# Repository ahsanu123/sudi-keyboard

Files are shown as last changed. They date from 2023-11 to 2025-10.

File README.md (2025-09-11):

 <p >
  <a href="">
    
  </a>
  
  <a href="">
    
  </a>
  
  <a href="">
    
  </a>
  
  <a href="https://github.com/ahsanu123/sudi-keyboard/blob/main/LICENSE">
    
  </a>

  <a href=" ">
    
  </a>
  
</p>

<p style="align: right;">
   
</p>
 
# 🌿 _Sudi_ V2

Sudi V2 is custom wireless split keyboard based on NRF52832 Nordic Semiconductor Microcontroller series, each side consist 18 keys 36 in totals, use MCP23017 I2C 
I/O expansion to scan one side of keyboard, and use wire to trasfer data to NRF52. Built in SWD debug port, with Serial Logger based on CH340G. Sudi Have interactive 
RGB LED and OLED 0.91 inch for graphic display. Planned to create 3D print enclosure.

## 💾 hardware 
hardware is designed with Kicad, you can find out hardware design in `pcb-design` folder. 

sudi schematic

**Over simplified workflow**
```mermaid
flowchart TD
    MatrixScanner[Matrix Scanner]
    COR[Chain Of Responsibility]
    FinalReport
    HIDBLEServer[BLE HID Server]

    MatrixScanner --> COR
    COR --> FinalReport
    FinalReport --> HIDBLEServer
```

<details>
  <summary>Casing Design</summary>
 
   

</details>

## 🔥 Progress Log


<details>
  <summary>expand this to see current progress 🍰 </summary>

- ~~try to understand why linker script flash ram address need to change from `0x8000` to `0x4000` [look this thread](https://devzone.nordicsemi.com/f/nordic-q-a/78577/nrf-sdk-pre-built-blinky-hex-works-compiled-hex-does-not-nrf51822)~~, use Zephyr instead.
- ~~update hardware readme.md section, add schematic svg~~
- ~~try to logging with segger jlink rtt~~ at 9 september 2024 22:09
- try to logging with serial logger
- ~~add usb to serial (ch340g) if serial logger worked /or considering to use segger rtt (worked and tested on NRF51822)~~
- ~~add on off switch for board~~
- ~~🦀 Change design to use NRF52832~~
- 🔥 Learn more about Zephyr
- ~~change JTAG debugger to component with less space and same pinout based on JLink v8 pinout.~~
- 🔋 ~~battery/and its charger need adjustment, because NRF5232 power supply range is 1.7 V to 3.6 V , and TP4056 will shutdown on 4.2V. if you add AMS1117 3.3v to regulate it, AMS1117 need at least 4.5V to maintain its 3.3V.~~ (NAH, use buck boost instead)
- 🔋 read about BQ24075 bms datasheet
- 🔋 Read about  MAX17048  datasheet
- 🔋 ~~if we use 1.8V for NRF Voltage supply, how its affect other used component~~
  - 🪔 ~~WS2812 VIO level was not satisfied, based on its datasheet, min supply is 3.5, VIH 0.7*VDD (2.45), VIL 0.3 *VDD (1.05)~~
  - ⚗️ ~~based on MCP23017 datashet its power voltage range is 1.8V to 5.5v, VIH 0.25 VDD + 0.8, VIL 0.8 VDD, so its possible to use MCP23017 with 1.8V NRF voltage supply,~~
  - 🐤 ~~CH340G~~
- ~~🔶check 4 pin crystal compatibility~~
- 🦄 ~~change MCU to use NRF52833?? (power supply 1.7-5.5), usb, price +1 dollar 😥, or (NRF52820 only $2.6348)~~
- 🧀 ~~Recheck Silk Screen and componnent~~
- 💸 ~~Create Manufacture id BOM, and Order it~~ about 70 dollar
- 💸 ~~wait dollar until it lower, and order all needed component.~~ shit!!!, dollar does not decline
- ⚽ ~~Final Re-Inspection~~ not doing it actually
- 💸 ~~ordered pcb. 5 Pcs for $15.72 with shipment 7.02 dollar and the pcb is 8.7, still wait for tax. ⏰ 19 januari 2025 at 22:16,~~ arrived in 7 Februari
- 👘 Ordering Component 58 dollar free shipping ( shipping is 7 dollar) , ⏰ 8 Februari 2025
- 💼 Casing - Left Right Connector
- 💼 Casing - top fastener
- 💼 Casing - Battery Holder
- 28 April 2025 ⏰ 05:47, finish one side small component soldering, there is still a lot solder bridge, need to recheck before aplying power
- 🐞 **BUG**, 1 Mei 2025 ⏰17:29, cell pin need to connect into battery pin, not 3.3v

  
  
- 🐞 **BUG**, 9 Mei 2025 ⏰ 20:18 current version 2 gerber used for manufacturing pcb is not updated, there is shorted between 3.3v and gnd
- 🐞 **BUG**, 13 Mei 2025 ⏰ 06:52 look and re-calculate inductor 5v buck-boost, when its at full load (all ws28 12 is on) inductor is burn, but ic is not.

> change inductor to use power inductor like VLF4012-2R2 (2.2uH, 1.5A), or choose same capacitance with higher current rate.
>
> look this [lcsc power inductor](https://www.lcsc.com/product-detail/Power-Inductors_MetalLions-MTQH201608S2R2MBT_C17701122.html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)

- 🎰 able to run and flash RMK example with jlink and probe-rs ⏰ 9 Mei 2025, 20:19
- basic setup on WSL, so able to develop in WSL ⏰ 20 Mei 2025, 05:26

  to debugging you need bridge usb device from windows to wsl with `usbipd`

  ```shell
  C:\Windows\System32> usbipd list
  Connected:
  BUSID  VID:PID    DEVICE                                                        STATE
  1-1    feed:0ffa  USB Input Device                                              Not shared
  1-2    0000:3825  USB Input Device                                              Not shared
  1-4    0bda:0129  Realtek USB 2.0 Card Reader                                   Not shared
  1-5    13d3:56cb  USB2.0 HD IR UVC WebCam                                       Not shared
  1-6    1366:0101  J-Link driver                                                 Not shared
  1-10   8087:0026  Intel(R) Wireless Bluetooth(R)                                Not shared

  Persisted:
  GUID                                  DEVICE

  C:\Windows\System32> usbipd bind --busid 1-6

  C:\Windows\System32> usbipd attach --wsl --busid 1-6
  usbipd: info: Using WSL distribution 'Arch' to attach; the device will be available in all WSL 2 distributions.
  usbipd: info: Detected networking mode 'nat'.
  usbipd: info: Using IP address 172.27.144.1 to reach the host.

  C:\Windows\System32>
  ```

  then you can access the usb device as in linux

- 24 Mei 2025, trying to run trouble bas example, its give good sign, even 5v sepic is died for now -> https://github.com/embassy-rs/trouble/blob/main/examples/apps/src/ble_bas_peripheral.rs ⏰ 09:01 

- 25 Mei 2025, able to read uuid for battery level on trouble bas example, also create basic reading uuid with bleak python library, but its really intermitent, bluez is more robust, several note to use and connect bluez with device.

also flashed firmware is from trouble example, current v2 firmware is compiled but not running, 🪞 need to investigate it

```shell
$ bluetoothctl
hci0 new_settings: powered bondable ssp br/edr le secure-conn
Agent registered

[bluetoothctl]> connect FF:E4:05:1A:8F:FF
[bluetoothctl]> disconnect FF:E4:05:1A:8F:FF
[bluetoothctl]> menu gatt
[bluetoothctl]> list-attributes
[bluetoothctl]> select-attribute /org/bluez/hci0/dev_FF_E4_05_1A_8F_FF/service0020/char0021
[bluetoothctl]> read
[bluetoothctl]>
```

- 3 Juli 2025, reading more about trouble, here is `trouble-host-macro` documentation located https://docs.rs/trouble-host-macros/latest/trouble_host_macros/ , here are some note
  - Peripherals may use **GATT** (Generic Attribute Profile) to expose **services** and **characteristics**,
  - still many question about why linker cant linking ble exampl (stack is overflow) even though its identical with example
  - this error ` cannot move location counter backwards (from 3ffdeca8 to 3ffdc000` is because `embassy-executor` `task-arena-<size>` i am not sure why and what value its shouuld be. but without defining task arena its compiled but `panic` on runtime.
  - ok, i find out making `embassy-executor` have `embassy-executor = { version = "0.7.0", features = ["task-arena-size-8192"]}` will make it compiled 😙, need to learn what is that.

finally at ⏰ 21:46 its compiled and able to run, its discoverable with phone 


- 23 Agustus 2025, finally my first SUDI was broke (MCU) and I must finish SUDI v2 for working.
- 24 agustus 2025, basic bas for nrf is compiled and flashed, ⏰ 13:25 
  

  ⏰ 21:29, able to advertise device as bluetooth hid, but still cant establishing connection to keyboard,
  need to understand how HID keyboard is connected in USB and in BLE.

- 11 September 2025, after reading more about BLE spesification, to more understand what each endpoint / characteristic does in BLE HID, you need to:
  * read characteristic code from [bluetooth assigned number](http://bluetooth.com/wp-content/uploads/Files/Specification/HTML/Assigned_Numbers/out/en/Assigned_Numbers.pdf). for example look at `2a4a` from `hid_info` property in this struct (take from RMK github)
    ```rust
    #[gatt_service(uuid = service::HUMAN_INTERFACE_DEVICE)]
    pub(crate) struct HidService {
        #[characteristic(uuid = "2a4a", read, value = [0x01, 0x01, 0x00, 0x03])]
        pub(crate) hid_info: [u8; 4],
        #[characteristic(uuid = "2a4b", read, value = KeyboardReport::desc().try_into().expect("Failed to convert KeyboardReport to [u8; 67]"))]
        pub(crate) report_map: [u8; 67],
        #[characteristic(uuid = "2a4c", write_without_response)]
        pub(crate) hid_control_point: u8,
        #[characteristic(uuid = "2a4e", read, write_without_response, value = 1)]
        pub(crate) protocol_mode: u8,
        #[descriptor(uuid = "2908", read, value = [0u8, 1u8])]
        #[characteristic(uuid = "2a4d", read, notify)]
        pub(crate) input_keyboard: [u8; 8],
        #[descriptor(uuid = "2908", read, value = [0u8, 2u8])]
        #[characteristic(uuid = "2a4d", read, write, write_without_response)]
        pub(crate) output_keyboard: [u8; 1],
    }
    ```
  * search `2a4a` on BLE Assigned number you will find **HID Information**
    
  * from that information (HID Information), look at [HID over gatt profile](https://www.bluetooth.com/specifications/specs/hid-over-gatt-profile-1-0/)
    
  * it will give you basic information of what is **HID information** is
  * to understand more about what value should provided by your device, you can continue to [Device Class Definition for HID](https://www.usb.org/sites/default/files/hid1_11.pdf), and try to search keyword from _HID over gatt profile_ description, for example `bcountryCode`, search on _Device class definition for HID_ then you will find **HID Descriptor**
    
  * from that information you can conclude `value = [0x01, 0x01, 0x00, 0x03])]` is HID Descriptor, then
  * `0x01` is _bLength_
  * `0x01` is _bDescriptorType_
  * `0x00` is _bcdHID_
  * `0x03` is _bCountryCode_
</details>

## 💳 Reference 

- [RMK - Rust Keyboard Firmware](https://github.com/HaoboGu/rmk/tree/main)   
- [Buck Boost for 3.3v](https://www.eevblog.com/forum/projects/regulating-lipo-battery-to-3-3v/)

<sup>🔥 make it V2 - 19 juni 2024 10:49</sup>

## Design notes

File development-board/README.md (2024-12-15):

## SUDI Development Board

Development board intended to understanding NRF52 nordic series for wireless keyboard, 
with Battery Management System (BMS), Bluetooth Low Energy Communication, USB, Vsense and 
LED Matrix.

## Description 

initial design decision, 

- NRF52820(5v tolerant, and USB, 256 kB flash, 32 kB RAM, QFN-40-EP(5x5), $2.6)
- NRF52832(**No** 5v tolerant, and **No** USB, 512/256 kB flash, 64/32 kB RAM, QFN-48-EP(6x6), $2.75)
- NRF52833QDXX(5v tolerant, and USB, 512 kB flash, 128 kB RAM, QFN-40-EP(5x5), $3.59)
- NRF52840(5v tolerant, and USB, 1 MB flash, 256 kB RAM, WLCSP-94(3.5x3.6) More difficult to Solder but most complete feature, $5.22)
- Add BMS into board 
- add IO expander, use MCP23017 smd
- board able to drive ws2812b (min voltage 3.5)
- vsense ic MAX17048
- switch to test 
- led for indicator 
- give all pin connector 
- usb with protection 
- uart 
- i2c 

## Note 

- [NRF51822 bluetooth module pin](https://quartzcomponents.com/cdn/shop/products/NRF51822-BLE-Module_1200x1200.jpg?v=1653290384)
  
```schell
left (from top perspectife, count from bottom)      Right (from top perspectife, count from bottom)  
PO3                                                 PO105                                            
PO4                                                 PO106                                            
PO1                                                 PO107                                            
PO2                                                 PO108                                            
PO30                                                PO109                                            
PO0                                                 PO110                                            
VDD                                                 PO111                                            
GND                                                 PO112                                            
PO28                                                PO003                                            
PO29                                                PO114                                            
NC                                                  PO015                                            
NC                                                  PO116                                            
PO24                                                SDA                                              
PO25                                                SCLK                                             
PO22                                                PO117                                            
PO23                                                PO119                                            
GND                                                 PO118                                            
PO21                                                PO200                                            

```

## Reference 

- [ebastler/zmk-designguide](https://github.com/ebastler/zmk-designguide)

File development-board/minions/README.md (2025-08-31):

# Minions


[Assembly View](https://kicanvas.org/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)

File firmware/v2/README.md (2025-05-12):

# Introduction

## Pinout 



## Note 

- to custom cargo subcommand use `Makefile.toml` with `cargo-make`, `cargo make some-task`

## Reference 

- [flash softdevice (bluetooth stack by nordic, closed source), only flash once](https://github.com/embassy-rs/nrf-softdevice#running-examples)

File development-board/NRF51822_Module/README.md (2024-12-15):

## Introduction 

Place to save Zephyr learning with NRF51822 Module

## Setup 

- after install dependencies like cmake, devicetree, and python
- create new python Environment with `venv` on home directory for example (`~/zephyr-sdk/`), 
- run `python -m venv ~/zephyr-sdk/.venv/`
- then activate it with `source ~/zephyr-sdk/.venv/bin/activate`
- next install **west** with `pip`, run `pip install west`

## Note 

- change default Zephyr SDK installation folder with env variable [ZEPHYR_SDK_INSTALL_DIR](https://docs.zephyrproject.org/latest/develop/env_vars.html#envvar-ZEPHYR_SDK_INSTALL_DIR) 
- important Zephyr concept

> [!NOTE]
> In this document, we’ll assume:
> your application directory, `<app>`, is something like `<home>/zephyrproject/app`
> its build directory is `<app>/build`
> These terms are defined below. On Linux/macOS, `<home>` is equivalent to `~`. On Windows, it’s `%userprofile%`.
> Keeping your application inside the workspace (`<home>/zephyrproject`) makes it easier to use west build and other commands with it. (You can put your application anywhere as long as [ZEPHYR_BASE](https://docs.zephyrproject.org/latest/develop/application/index.html#important-build-vars) is set appropriately, though.)

| Application type | <app> location |
|---|---|
| repository | zephyr repository |
| workspace | west workspace where Zephyr is installed |
| freestanding | other locations |

### Note on Make Custom Board (Porting)

root folder is `app`

```shell
boards/
soc/
CMakeLists.txt
prj.conf
README.rst
src/
```

```shell
.
├── boards
│   └── vendor
│       └── my_custom_board
│           ├── doc
│           │   └── img
│           └── support
└── src
```

The contents of my_custom_board should follow the same guidelines for any Zephyr board,
```shell
// inside board folder name (/boards/<vendor>/<board-name>/)
my_custom_board_defconfig
my_custom_board.dts
my_custom_board.yaml
board.cmake
board.h
CMakeLists.txt
doc/
Kconfig.my_custom_board
Kconfig.defconfig
support/
```

- **Board YAML**

> [!NOTE]
> The board YAML file describes the board at a high level. This includes the SoC, board variants, and board revisions.
> Detailed configurations, such as hardware description and configuration are done in devicetree and Kconfig.

## Log

- Make personal note on how to setup Zephyr Environment with poetry

## Reference 

- [official bluetooth learning resource](https://www.bluetooth.com/bluetooth-resources/?types=study-guide)
- [zephyr board porting guide](https://docs.zephyrproject.org/latest/hardware/porting/board_porting.html)
- [Custom Board devicetree and SOC Definitions](https://docs.zephyrproject.org/latest/develop/application/index.html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)

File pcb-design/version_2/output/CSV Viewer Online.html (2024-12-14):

| Id | Designator | Footprint | Quantity | Designation | Supplier and ref | | H
1 | 1 | C56,C11,C15 | C_0805_2012Metric_Pad1.18x1.45mm_HandSolder | 3 | 0.1uF / 100nF | | | in stock
2 | 2 | K16,K9,K8,K18,K12,K14,K7,K6,K5,K2,K10,K13,K3,K15,K17,K4,K11,K1 | Kailh_socket_MX_optional_reversible_platemount | 18 | KEYSW | | | buy local
3 | 3 | FB1 | L_0603_1608Metric_Pad1.05x0.95mm_HandSolder | 1 | 60R@100Mhz | | | ok
4 | 4 | R10,R17,R15 | R_0805_2012Metric_Pad1.20x1.40mm_HandSolder | 3 | 1K | | | in stock
5 | 5 | TP16 | TestPoint_Pad_D1.0mm | 1 | 29 | | | not need
6 | 6 | C51,C42,C41,C43,C40,C19,C39,C20,C54,C44,C45,C52,C35,C48,C53,C47,C50,C46,C49,C55,C38 | C_0805_2012Metric_Pad1.18x1.45mm_HandSolder | 21 | 100nF | | | in stock
7 | 7 | J1,J5 | USB_C_Receptacle_GCT_USB4125-xx-x-0190_6P_TopMnt_Horizontal | 2 | SIDE_CON | | | in stock
8 | 8 | D17,D18,D25,D8,D36,D29,D31,D9,D38,D10,D24,D19,D30,D23,D13,D37,D12,D11 | LED_WS2812B-2020_PLCC4_2.0x2.0mm | 18 | WS2812B | | | ok
9 | 9 | C3,C1 | C_0805_2012Metric_Pad1.18x1.45mm_HandSolder | 2 | 4.7uF | | | ok
10 | 10 | FID9,FID2,FID3,FID6,FID7,FID5,FID1,FID8,FID4 | Fiducial_1mm_Mask3mm | 9 | Fiducial | | | -
11 | 11 | D26,D33,D2,D21,D34,D14,D7,D1,D20,D15,D5,D27,D3,D16,D35,D22,D28,D6 | D_SOD123_axial-dual | 18 | 1N4148 | | | ok
12 | 12 | H2,H1,H5,H3,H4,H7,H6 | MountingHole_3.2mm_M3_DIN965_Pad | 7 | MountingHole_Pad | | | -
13 | 13 | TP5 | TestPoint_Pad_D1.0mm | 1 | 4 | | | not need
14 | 14 | R4,R3 | R_0805_2012Metric_Pad1.20x1.40mm_HandSolder | 2 | 5K1 | | | ok
15 | 15 | C18,C8 | C_0805_2012Metric_Pad1.18x1.45mm_HandSolder | 2 | 12pF | | | ok
16 | 16 | TP17 | TestPoint_Pad_D1.0mm | 1 | 30 | | | not need
17 | 17 | R11 | R_0805_2012Metric_Pad1.20x1.40mm_HandSolder | 1 | 1k | | | in stock
18 | 18 | TP9 | TestPoint_Pad_D1.0mm | 1 | 22 | | | not need
19 | 19 | R12,R5 | R_0805_2012Metric_Pad1.20x1.40mm_HandSolder | 2 | 100k | | | in stock
20 | 20 | AE1 | Texas_SWRA117D_2.4GHz_Left | 1 | 2.4GHz | | | -
21 | 21 | C2 | C_0805_2012Metric_Pad1.18x1.45mm_HandSolder | 1 | 10uF/5V | | | in stock
22 | 22 | TP13 | TestPoint_Pad_D1.0mm | 1 | 26 | | | not need
23 | 23 | R1,R2 | R_0805_2012Metric_Pad1.20x1.40mm_HandSolder | 2 | 4K7 | | | in stock
24 | 24 | TP11 | TestPoint_Pad_D1.0mm | 1 | 24 | | | not need
25 | 25 | P1 | USB_C_Receptacle_GCT_USB4105-xx-A_16P_TopMnt_Horizontal | 1 | USB_C_Plug_USB2.0 | | | ok
26 | 26 | TP3 | TestPoint_Pad_D1.0mm | 1 | 2 | | | not need
27 | 27 | C21 | C_0805_2012Metric_Pad1.18x1.45mm_HandSolder | 1 | 0.8pF | | | in stock
28 | 28 | R14 | R_0805_2012Metric_Pad1.20x1.40mm_HandSolder | 1 | 1.13k | | | in stock
29 | 29 | U7 | QFN-48-1EP_6x6mm_P0.4mm_EP4.6x4.6mm | 1 | nRF52832-QFxx | | | ok
30 | 30 | TP15 | TestPoint_Pad_D1.0mm | 1 | 28 | | | not need
31 | 31 | Y1 | Crystal_SMD_2016-4Pin_2.0x1.6mm | 1 | 32MHz_CF4032M00020001 | | | ok
32 | 32 | U5 | VQFN-16-1EP_3x3mm_P0.5mm_EP1.6x1.6mm | 1 | BQ24075RGT_DPPM | | | ok
33 | 33 | C36 | C_0805_2012Metric_Pad1.18x1.45mm_HandSolder | 1 | 100nF/NC | | | in stock
34 | 34 | Q2 | SOT-23 | 1 | PJA3405_(G1,D3,S2) | | | ok
35 | 35 | D4 | LED_0805_2012Metric_Pad1.15x1.40mm_HandSolder | 1 | green | | | ok
36 | 36 | TP18 | TestPoint_Pad_D1.0mm | 1 | 31 | | | not need
37 | 37 | C37 | C_0805_2012Metric_Pad1.18x1.45mm_HandSolder | 1 | 1uF | | | in stock
38 | 38 | TP4 | TestPoint_Pad_D1.0mm | 1 | 3 | | | not need
39 | 39 | R6 | R_0805_2012Metric_Pad1.20x1.40mm_HandSolder | 1 | 46.4K | | | in stock
40 | 40 | TP8 | TestPoint_Pad_D1.0mm | 1 | 20 | | | not need
41 | 41 | TP2 | TestPoint_Pad_D1.0mm | 1 | 1 | | | not need
42 | 42 | TP1 | TestPoint_Pad_D1.0mm | 1 | 0 | | | not need
43 | 43 | TP6 | TestPoint_Pad_D1.0mm | 1 | 5 | | | not need
44 | 44 | SW3 | SW_SPDT_PCM12 | 1 | PWR_SWITCH | | | ok
45 | 45 | TP12 | TestPoint_Pad_D1.0mm | 1 | 25 | | | not need
46 | 46 | R7 | R_0805_2012Metric_Pad1.20x1.40mm_HandSolder | 1 | 1.18k | | | in stock
47 | 47 | TP10 | TestPoint_Pad_D1.0mm | 1 | 23 | | | not need
48 | 48 | D32 | LED_0805_2012Metric_Pad1.15x1.40mm_HandSolder | 1 | red | | | ok
49 | 49 | Q1 | SOT-23 | 1 | PJA3404_(G1,D3,S2) | | | ok
50 | 50 | TP7 | TestPoint_Pad_D1.0mm | 1 | 19 | | | not need
51 | 51 | L3 | L_0603_1608Metric_Pad1.05x0.95mm_HandSolder | 1 | 3.9nH | | | ok
52 | 52 | J3 | PinHeader_1x04_P2.54mm_Vertical | 1 | 0.91 OLED | | | -
53 | 53 | TP14 | TestPoint_Pad_D1.0mm | 1 | 27 | | | not need
54 | 54 | SW4 | SW_SPDT_PCM12 | 1 | 5V_EN | | | ok
55 | 55 | J2 | PinHeader_1x04_P2.54mm_Horizontal | 1 | SWD_JLINK | | | -
56 | 56 | C17,C13,C14,C12,C16,C4 | C_0805_2012Metric_Pad1.18x1.45mm_HandSolder | 6 | 10uF | | | ok
57 | 57 | U4 | SOIC-16_3.9x9.9mm_P1.27mm | 1 | CH340C | | | in stock
58 | 58 | SW1 | SW_Push_1P1T_NO_6x6mm_H9.5mm | 1 | RST | | | in stock

| Id | Designator | Footprint | Quantity | Designation | Supplier and ref | | H

1

2

3

4

5

6

7

8

9

10

11

12

13

14

15

16

17

18

19

20

21

22

23

24

25

26

27

28

29

30

31

32

33

34

35

36

37

38

39

40

41

42

43

44

45

46

47

48

49

50

51

52

53

54

55

56

57

58

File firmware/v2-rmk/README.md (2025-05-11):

# ⌨️ Sudi With RMK 

Try to understand and implement RMK for Sudi, make contribution if possible.

## 🦀 RMK Note 

**RMK File Summary**

- 📁 ble
- 📁 config
- 📁 input_device
- 📁 split
- 📁 storage
- 📁 usb
- 📁 via
- 🍉 action.rs -> contain struct and function to convert action into real binary keyboard command
- 🍉 boot.rs -> contain basic boot operation, jump to bootloader and reboot keyboard
- 🍉 channel.rs -> contain multithread channel, signal, mutex and pubsub. mostly from embassy_sync lib
- 🍉 combo.rs -> contain struct to implement keyboard combo feature
- 🍉 direct_pin.rs -> contain struct that define structure of keyboard matrix,
> [!NOTE]
>
> directPinMatrix contain 2 method, `read_event` and `wait_for_key`.
>
> if `async_matrix` is use, `read_event` will wait for key (wait for keyboard user to typing on key), based on setting, switch matrix may active low or active high, inside  `wait_for_key` program will use `select_slice` from `embassy_future::select` to wait any key to be low/high then it will continue process in `read_event` method.
>
> if `async_matrix` is not used program will run loop scanning inside `read_event` method every `100 micro second` as indicated by `Timer::after_micros(100).await;` it will use debouncer to detect if debounce happen, then it will return `Event`.
> 
> (need read more about this method, and its logic)

- 🍉 event.rs -> contain struct of Event, event is not only coming from keyboard typing, but also several other type.
- 🍉 fmt.rs -> contain format for doing debug, loging, or print information
- 🍉 fork.rs -> not trully understand what is this 
- 🍉 hid.rs -> contain HID struct and trait to be implemented by concrete peripheral like USB or BLE 
- 🍉 hid_state.rs -> contain HID state like, HID modifier, HID Mouse button (need read more about HID)
- 🍉 keyboard.rs -> i think its center logic, its big file and lot of test too, need to deep dive into it.
- 🍉 keyboard_macro.rs -> define sturcture, logic and test of _keyboard macro_ (key combination / sequence operation with one key press)
- 🍉 keycode.rs -> contain all HID keycode
- 🍉 keymap.rs -> define logic of keymap (key layer, what key will do when it pressed)
- 🍉 layout_macro.rs -> contain lot of macro, still dont understand well on reading `macro_rules`
- 🍉 lib.rs -> contain library utility function, and exported API to enduser
- 🍉 light.rs -> contain led controller, need read more about logic on this file 
- 🍉 matrix.rs -> i think its high level for abstraction of `direct_pin.rs`
- 🍉 state.rs -> contain keyboard connection state (BLE, or USB), its like, its keyboard connected??

## 🍈 References 

- [cfg attribute](https://doc.rust-lang.org/rust-by-example/attribute/cfg.html)

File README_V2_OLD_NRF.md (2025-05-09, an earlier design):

<h1 align="center">🌿 <i>SUDI</i> Keyboard V2</h1>
<p style="align: right;">
   
  
</p>

<p >
  <a href="">
    
  </a>
  <a href="">
    
  </a>
  <a href="">
    
  </a>
  <a href="https://github.com/ahsanu123/sudi-keyboard/blob/main/LICENSE">
    
  </a>
</p>

Sudi V2 is custom wireless split keyboard based on NRF52832 Nordic Semiconductor Microcontroller series, each side consist 18 keys 36 in totals, use MCP23017 I2C I/O expansion to scan one side of keyboard, and use wire to trasfer data to NRF52. Built in SWD debug port, with Serial Logger based on CH340G. Sudi Have interactive RGB LED and OLED 0.91 inch for graphic display. Planned to create 3D print enclosure.\

<details>
  <summary>Casing Design</summary>
 
   

</details>

## 🖨️ Compile And Flash

🍮 Step to Compile and flash (Zephyr)

first activate your python environtment (i use micromamba, sudiv2 is environtment on my linux pc) 
```shell
micromamba activate sudiv2
```
next build with `west` 
```shell
west build -b sudi app
```

---

🍮 Step to Compile and flash (Makefile and Native toolchain)

1. because we use makefile just call `make` in root directory
2. after complete you can use jlink or stlink to program your binary, nrf can programmed with swd
3. to use jlink you can use this command `sudo JLinkExe -Device NRF51822_XXAA -IF swd -AutoConnect 1 -Speed 1000` then you can load binary file with `loadfile ./path/to/file.out` (we use .out instead .elf)
4. to use stlink you can use this [script](https://github.com/vedderb/nrf51_vesc) you need change .out path
```shell
#!/bin/bash
openocd -f openocd.cfg -c "init" \
  -c "halt" \
  -c "nrf51 mass_erase" \
  -c "program ./build/binary.out verify reset exit"
```

## 🐞 Debugging Step

there is many way to debug NRF microcontroller, i will use JLink V8. first connect Jlink SWD to NRF MCU. 

after compile, upload your binary with jlink 
```shell
 sudo JLinkExe -Device NRF51822_XXAA -IF swd -AutoConnect 1 -Speed 1000 // change device based on your device
```
next inside `JLinkExe` run load binary file with `loadfile ./path/to/your/file.elf` (you can automate this with text script, but i just want write it to remember).

then start `openocd` debug server with

```shell
sudo openocd -f interface/jlink.cfg  -c "transport select swd; adapter speed 1000" -f target/nrf51.cfg &
```

finally you can start your debugger in this case we use `arm-none-eabi-gdb` then connect to target with this step (withtout `>`)

```shell
> file ./path/to/your/file.elf
> break main.c:22 //optional
> target extended-remote :3333 // default port for openocd debug server
> // devices connected
```

if debugger will _stuck_ on `fail.c` after _arch interrupt lock_ there maybe some bad/wrong setting(recheck your config).

<details>
  <summary>🍷 Old Debug Step (here for history purpose only)</summary>
  
  to debug you can use openocd + stlink, openocd + jlink, ozone. make sure to change `gdbcmd.txt` based on your setting (gdb port, output filename, etc.)

```shell
//🗒️🗒️🗒️🗒️ gdbcmd.txt 🗒️🗒️🗒️🗒️🗒️
// you need to connect into server first before choosing `file` to debug, 
target extended-remote :3333
file ./build/nrf51822_xxaa.out
break main
continue
```

- openocd + stlink
  first start openocd gdb server with this command
  
 ```shell
   sudo openocd -f interface/stlink-v2.cfg -f target/nrf51.cfg &
  ```
 
  next you can use `arm-none-eabi-gdb` to debug your program, run this command on other terminal `arm-none-eabi-gdb -x gdbcmd.txt`

- openocd + jlink
 you can start jlink gdb server with this command `sudo JLinkGDBServerExe &` then choose device and peripheral (swd) , or you can start server with openocd

 ```shell
  sudo openocd -f interface/jlink.cfg  -c "transport select swd; adapter speed 1000" -f target/nrf51.cfg
  ```

  next you can use `arm-none-eabi-gdb` to debug your program, run this command on other terminal `arm-none-eabi-gdb -x gdbcmd.txt`
  
- ozone
  last option you can use segger ozone. (not trying yet)
</details>

<details>
  <summary>expand this if you curious (historic purpose only)</summary>
  
- **Ok!!**, I need 2 days (on my weekend) for figuring out how compile in NRF51 mcu with NRF5 SDK (at time of writing NRF5 SDK was obsolete/under maintenance only by Nordic Semiconductor). 

- **FIRST** as far as i understand NRF51 MCU series only work with NRF5 sdk below version 12 (never complete compiling with version above 12), so you need to download NRF5 SDK version 12 or below. 

- **SECOND** i have try to compile nrf project with cmake, but fail and make me stress, so i stick with makefile

- **THIRD** debugging with `arm-eabi-none-gdb` a bit tricky you need perform several command before program go into breakpoint.

- **FOURTH** you need to use old gcc compiler (gcc-arm-none-eabi-4_9-2015q3-20150921-linux.tar.bz2), there is some problem in linking process when you use new gcc version like v14
</details>

## 💾 hardware 
hardware is designed with Kicad, you can find out hardware design in `pcb-design` folder. 
sudi schematic

casing is designed with PTC CREO, and use cutting acrylic (not uploaded/complete yet but planned)  
<details>
  <summary>Expand Me </summary>
  <p align="center">
  <a href="https://youtu.be/LN7CI2rUKP8">
    
  </a>
</p>

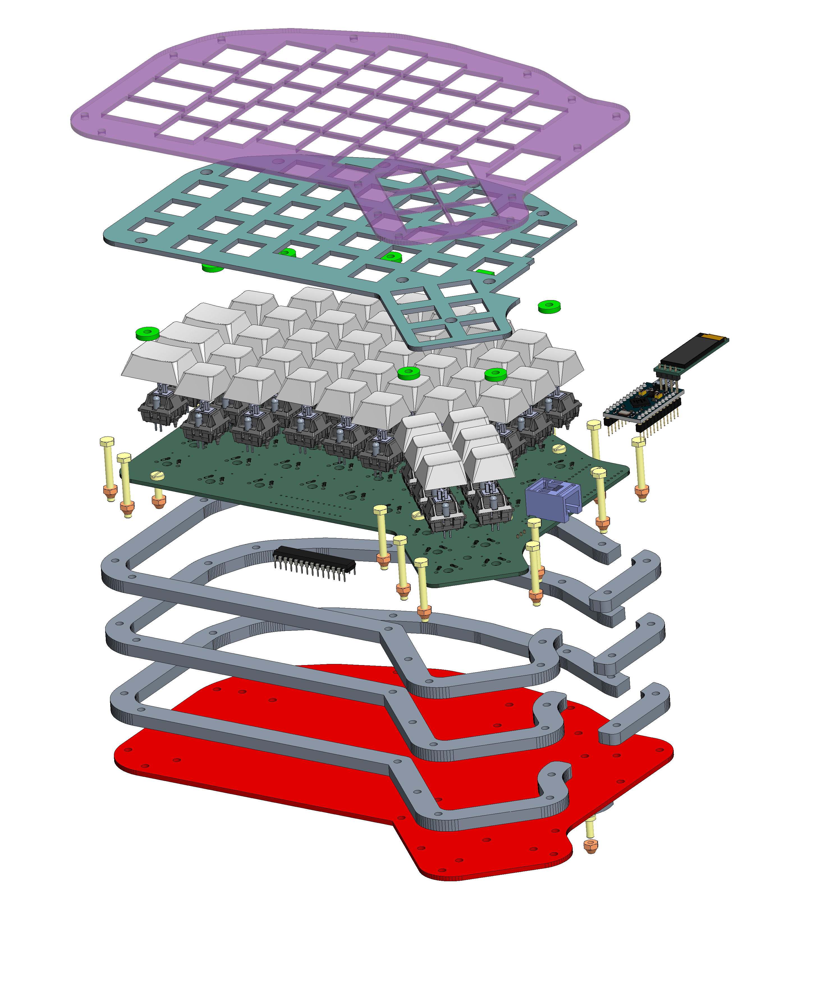
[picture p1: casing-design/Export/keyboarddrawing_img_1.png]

</details>

## 🧁 Install Module In Zephyr
zephyr use _manifest_(west.yml) to setting what module used. to automatic install module, add module name after `name-allowlist`, here is example.

```yaml
manifest:
  self:
    west-commands: scripts/west-commands.yml

  remotes:
    - name: zephyrproject-rtos
      url-base: https://github.com/zephyrproject-rtos

  projects:
    - name: zephyr
      remote: zephyrproject-rtos
      revision: main
      import: 
        name-allowlist:
          - cmsis      # required by the ARM port
          - hal_nordic # required by the custom_plank board (Nordic based)
          - hal_stm32  # required by the nucleo_f302r8 board (STM32 based)
          - segger # add another component based on module repository

```

after edit `west.yml` run `west update`, `west` will update the module based on manifest.

`west` will search to this [repo](https://github.com/zephyrproject-rtos/zephyr/tree/main/modules), then download and install it based on your zephyr root.

after you installed (download) zephyr module you can enable with `menuconfig`, you can run menuconfig with 
```shell
west build -t menuconfig
```

## 🧱 TODO List 


- ~~try to understand why linker script flash ram address need to change from `0x8000` to `0x4000` [look this thread](https://devzone.nordicsemi.com/f/nordic-q-a/78577/nrf-sdk-pre-built-blinky-hex-works-compiled-hex-does-not-nrf51822)~~, use Zephyr instead.
- ~~update hardware readme.md section, add schematic svg~~
- ~~try to logging with segger jlink rtt~~ at 9 september 2024 22:09
- try to logging with serial logger
- ~~add usb to serial (ch340g) if serial logger worked /or considering to use segger rtt (worked and tested on NRF51822)~~
- ~~add on off switch for board~~
- ~~🦀 Change design to use NRF52832~~
- 🔥 Learn more about Zephyr
- ~~change JTAG debugger to component with less space and same pinout based on JLink v8 pinout.~~
- 🔋 ~~battery/and its charger need adjustment, because NRF5232 power supply range is 1.7 V to 3.6 V , and TP4056 will shutdown on 4.2V. if you add AMS1117 3.3v to regulate it, AMS1117 need at least 4.5V to maintain its 3.3V.~~ (NAH, use buck boost instead)
- 🔋 read about BQ24075 bms datasheet
- 🔋 Read about  MAX17048  datasheet
- 🔋 ~~if we use 1.8V for NRF Voltage supply, how its affect other used component~~
  - 🪔 ~~WS2812 VIO level was not satisfied, based on its datasheet, min supply is 3.5, VIH 0.7*VDD (2.45), VIL 0.3 *VDD (1.05)~~
  - ⚗️ ~~based on MCP23017 datashet its power voltage range is 1.8V to 5.5v, VIH 0.25 VDD + 0.8, VIL 0.8 VDD, so its possible to use MCP23017 with 1.8V NRF voltage supply,~~
  - 🐤 ~~CH340G~~
- ~~🔶check 4 pin crystal compatibility~~
- 🦄 ~~change MCU to use NRF52833?? (power supply 1.7-5.5), usb, price +1 dollar 😥, or (NRF52820 only $2.6348)~~
- 🧀 ~~Recheck Silk Screen and componnent~~
- 💸 ~~Create Manufacture id BOM, and Order it~~ about 70 dollar
- 💸 ~~wait dollar until it lower, and order all needed component.~~ shit!!!, dollar does not decline
- ⚽ ~~Final Re-Inspection~~ not doing it actually
- 💸 ~~ordered pcb. 5 Pcs for $15.72 with shipment 7.02 dollar and the pcb is 8.7, still wait for tax. ⏰ 19 januari 2025 at 22:16,~~ arrived in 7 Februari
- 👘 Ordering Component 58 dollar free shipping ( shipping is 7 dollar) , ⏰ 8 Februari 2025
- 💼 Casing - Left Right Connector
- 💼 Casing - top fastener
- 💼 Casing - Battery Holder
- 28 April 2025 ⏰ 05:47, finish one side small component soldering, there is still a lot solder bridge, need to recheck before aplying power
- 🐞 **BUG**, 1 Mei 2025 ⏰17:29, cell pin need to connect into battery pin, not 3.3v
- 🐞 **BUG**, 9 Mei 2025 ⏰ 20:18 current version 2 gerber used for manufacturing pcb is not updated, there is shorted between 3.3v and gnd
- 🎰 able to run and flash RMK example with jlink and probe-rs ⏰ 9 Mei 2025, 20:19

  

## 💳 Reference 
- [you need to read this if blink example not working](https://devzone.nordicsemi.com/f/nordic-q-a/78577/nrf-sdk-pre-built-blinky-hex-works-compiled-hex-does-not-nrf51822)
- [NRF51 Series Documentation](https://www.nordicsemi.com/Products/nRF51822/GetStarted)
- [Redox-Keyboard](https://github.com/mattdibi/redox-keyboard) i use redox schematic for initial design  
- [MCP23017 datasheet](reference/MCP23017-20001952c.pdf) and add my *initial redox sch* with MCP23017
- [Zephyr Devices Tree](https://docs.zephyrproject.org/latest/build/dts/)
- [Buck Boost for 3.3v](https://www.eevblog.com/forum/projects/regulating-lipo-battery-to-3-3v/)
- [RMK - Rust Keyboard Firmware](https://github.com/HaoboGu/rmk/tree/main)

<sup>🔥 make it V2 - 19 juni 2024 10:49</sup>

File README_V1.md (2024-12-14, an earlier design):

# ⌨️ Sudi Keyboard V1


<!-- <img style="align: right; width: 50vw;" src="./pcb-design/output/sudi-redox-clone-RIGHT.png"> -->
Sudi keyboard is custom split keyboard based on QMK, its use MCP23017 for scanning key matrix on right side, use promicro for scanning left side. right now sudi is not come with rgb led but its planned.
each side consist 42 standard mechanical key, 84 in total. 

## 🔋 how to compile 
to build firmware you can follow qmk documentation on: https://docs.qmk.fm/#/newbs_building_firmware, create new keyboard then copy replace `sudi/firmware` to newly created qmk keyboard folder.
source code is copied and modified from mark story article: http://mark-story.com/posts/view/building-a-split-keyboard-part-3.  

## 💾 hardware 
hardware is designed with kicad, you can find out hardware design in `pcb-design` folder. 
- schematic: [sudi schematic](pcb-design/version_1/output/sudi-redox-keyboard-Schematic.pdf)

casing is designed with PTC CREO, and use cutting acrylic (not uploaded/complete yet but planned)  
<details>
  <summary>Expand Me </summary>
  <p align="center">
  <a href="https://youtu.be/LN7CI2rUKP8">
    
  </a>
</p>


</details>

## 💳 Reference 
- [Redox-Keyboard](https://github.com/mattdibi/redox-keyboard) i use redox schematic for initial design  
- [MCP23017 datasheet](reference/MCP23017-20001952c.pdf) and add my *initial redox sch* with MCP23017

<sup>🔥 make it V2 - 19 juni 2024 10:49</sup>

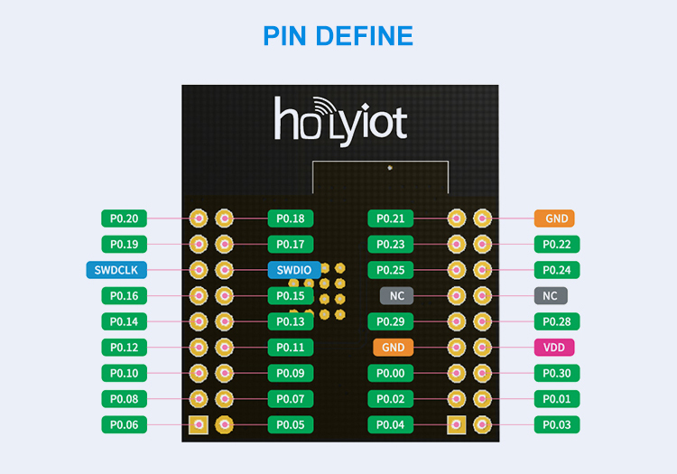
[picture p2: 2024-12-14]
reference/moduleBluetoothPinout.jpg

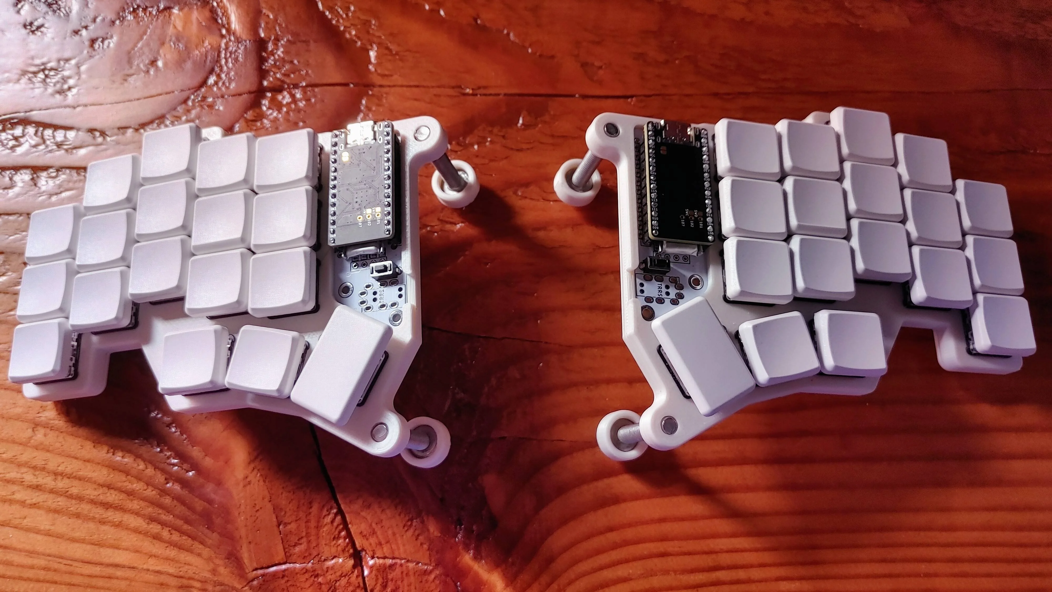
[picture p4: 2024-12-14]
reference/chocofiReference.webp

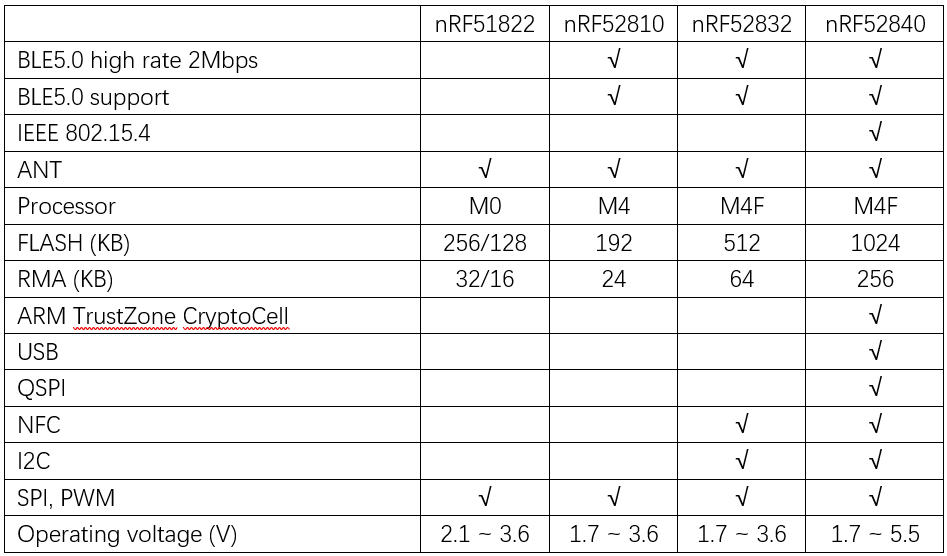
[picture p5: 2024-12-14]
reference/NRFTABLE_COMPARISON.png

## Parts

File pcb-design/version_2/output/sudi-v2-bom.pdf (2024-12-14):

Id | Designator | Footprint | Quantity | Designation | Supplier and ref | FIELD7 | FIELD8
1 | C56,C11,C15 | C_0805_2012Metric_Pad1.18x1.45mm_HandSolder | 3 | 0.1uF
2 | K16,K9,K8,K18,K12,K14,K7,K6,K5,K2,K10,K13,K3,K15,K17,K4,K11,K1 | Kailh_socket_MX_optional_reversible_platemount | 18 | KEYSW
3 | FB1 | L_0603_1608Metric_Pad1.05x0.95mm_HandSolder | 1 | 60R@100Mhz
4 | R10,R17,R15 | R_0805_2012Metric_Pad1.20x1.40mm_HandSolder | 3 | 1K
5 | TP16 | TestPoint_Pad_D1.0mm | 1 | 29
6 | C51,C42,C41,C43,C40,C19,C39,C20,C54,C44,C45,C52,C35,C48,C53,C47,C50,C46,C49,C55,C38 | C_0805_2012Metric_Pad1.18x1.45mm_HandSolder | 21 | 100nF
7 | J1,J5 | USB_C_Receptacle_GCT_USB4125-xx-x-0190_6P_TopMnt_Horizontal | 2 | SIDE_CON
8 | D17,D18,D25,D8,D36,D29,D31,D9,D38,D10,D24,D19,D30,D23,D13,D37,D12,D11 | LED_WS2812B-2020_PLCC4_2.0x2.0mm | 18 | WS2812B
9 | C3,C1 | C_0805_2012Metric_Pad1.18x1.45mm_HandSolder | 2 | 4.7uF
10 | FID9,FID2,FID3,FID6,FID7,FID5,FID1,FID8,FID4 | Fiducial_1mm_Mask3mm | 9 | Fiducial
11 | D26,D33,D2,D21,D34,D14,D7,D1,D20,D15,D5,D27,D3,D16,D35,D22,D28,D6 | D_SOD123_axial-dual | 18 | 1N4148
12 | H2,H1,H5,H3,H4,H7,H6 | MountingHole_3.2mm_M3_DIN965_Pad | 7 | MountingHole_Pad
13 | TP5 | TestPoint_Pad_D1.0mm | 1 | 4
14 | R4,R3 | R_0805_2012Metric_Pad1.20x1.40mm_HandSolder | 2 | 5K1
15 | C18,C8 | C_0805_2012Metric_Pad1.18x1.45mm_HandSolder | 2 | 12pF
16 | TP17 | TestPoint_Pad_D1.0mm | 1 | 30
17 | R11 | R_0805_2012Metric_Pad1.20x1.40mm_HandSolder | 1 | 1k
18 | TP9 | TestPoint_Pad_D1.0mm | 1 | 22
19 | R12,R5 | R_0805_2012Metric_Pad1.20x1.40mm_HandSolder | 2 | 100k
20 | AE1 | Texas_SWRA117D_2.4GHz_Left | 1 | 2.4GHz
21 | C2 | C_0805_2012Metric_Pad1.18x1.45mm_HandSolder | 1 | 10uF/5V
22 | TP13 | TestPoint_Pad_D1.0mm | 1 | 26
23 | R1,R2 | R_0805_2012Metric_Pad1.20x1.40mm_HandSolder | 2 | 4K7
24 | TP11 | TestPoint_Pad_D1.0mm | 1 | 24
25 | P1 | USB_C_Receptacle_GCT_USB4105-xx-A_16P_TopMnt_Horizontal | 1 | USB_C_Plug_USB2.0
26 | TP3 | TestPoint_Pad_D1.0mm | 1 | 2
27 | C21 | C_0805_2012Metric_Pad1.18x1.45mm_HandSolder | 1 | 0.8pF
28 | R14 | R_0805_2012Metric_Pad1.20x1.40mm_HandSolder | 1 | 1.13k
29 | U7 | QFN-48-1EP_6x6mm_P0.4mm_EP4.6x4.6mm | 1 | nRF52832-QFxx
30 | TP15 | TestPoint_Pad_D1.0mm | 1 | 28
31 | Y1 | Crystal_SMD_2016-4Pin_2.0x1.6mm | 1 | 32MHz_CF4032M00020001
32 | U5 | VQFN-16-1EP_3x3mm_P0.5mm_EP1.6x1.6mm | 1 | BQ24075RGT_DPPM
33 | C36 | C_0805_2012Metric_Pad1.18x1.45mm_HandSolder | 1 | 100nF/NC
34 | Q2 | SOT-23 | 1 | PJA3405_(G1,D3,S2)
35 | D4 | LED_0805_2012Metric_Pad1.15x1.40mm_HandSolder | 1 | green
36 | TP18 | TestPoint_Pad_D1.0mm | 1 | 31
37 | C37 | C_0805_2012Metric_Pad1.18x1.45mm_HandSolder | 1 | 1uF
38 | TP4 | TestPoint_Pad_D1.0mm | 1 | 3
39 | R6 | R_0805_2012Metric_Pad1.20x1.40mm_HandSolder | 1 | 46.4K
40 | TP8 | TestPoint_Pad_D1.0mm | 1 | 20
41 | TP2 | TestPoint_Pad_D1.0mm | 1 | 1

Id | Designator | Footprint | Quantity | Designation | Supplier and ref | FIELD7 | FIELD8
42 | TP1 | TestPoint_Pad_D1.0mm | 1 | 0
43 | TP6 | TestPoint_Pad_D1.0mm | 1 | 5
44 | SW3 | SW_SPDT_PCM12 | 1 | PWR_SWITCH
45 | TP12 | TestPoint_Pad_D1.0mm | 1 | 25
46 | R7 | R_0805_2012Metric_Pad1.20x1.40mm_HandSolder | 1 | 1.18k
47 | TP10 | TestPoint_Pad_D1.0mm | 1 | 23
48 | D32 | LED_0805_2012Metric_Pad1.15x1.40mm_HandSolder | 1 | red
49 | Q1 | SOT-23 | 1 | PJA3404_(G1,D3,S2)
50 | TP7 | TestPoint_Pad_D1.0mm | 1 | 19
51 | L3 | L_0603_1608Metric_Pad1.05x0.95mm_HandSolder | 1 | 3.9nH
52 | J3 | PinHeader_1x04_P2.54mm_Vertical | 1 | 0.91 OLED
53 | TP14 | TestPoint_Pad_D1.0mm | 1 | 27
54 | SW4 | SW_SPDT_PCM12 | 1 | 5V_EN
55 | J2 | PinHeader_1x04_P2.54mm_Horizontal | 1 | SWD_JLINK
56 | C17,C13,C14,C12,C16,C4 | C_0805_2012Metric_Pad1.18x1.45mm_HandSolder | 6 | 10uF
57 | U4 | SOIC-16_3.9x9.9mm_P1.27mm | 1 | CH340C
58 | SW1 | SW_Push_1P1T_NO_6x6mm_H9.5mm | 1 | RST
59 | U6 | Texas_DRC0010J_ThermalVias | 1 | TPS63002_SEPIC_5V
60 | L1,L2 | L_0603_1608Metric_Pad1.05x0.95mm_HandSolder | 2 | 22uH
61 | R16,R13 | R_0805_2012Metric_Pad1.20x1.40mm_HandSolder | 2 | 100
62 | J4 | PinHeader_1x02_P2.54mm_Horizontal | 1 | BatCon
63 | U8 | SSOP-28_5.3x10.2mm_P0.65mm | 1 | MCP23017_SS
64 | U9 | Texas_DRC0010J_ThermalVias | 1 | TPS63001_SEPIC_3V3
65 | U10 | DFN-8-1EP_2x2mm_P0.5mm_EP0.8x1.6mm | 1 | MAX17048

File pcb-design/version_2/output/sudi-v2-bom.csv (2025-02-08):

Reference | Value | Datasheet | Footprint | Qty | DNP
AE1,AE2 | 2.4GHz | ~ | RF_Antenna:Texas_SWRA117D_2.4GHz_Left | 2
C1,C3 | 4.7uF | ~ | Capacitor_SMD:C_0805_2012Metric_Pad1.18x1.45mm_HandSolder | 2
C2,C9,C22 | 10uF/5V | ~ | Capacitor_SMD:C_0805_2012Metric_Pad1.18x1.45mm_HandSolder | 3
C4,C12,C13,C14,C16,C17 | 10uF | ~ | Capacitor_SMD:C_0805_2012Metric_Pad1.18x1.45mm_HandSolder | 6
C5,C6 | 22pF | ~ | Capacitor_SMD:C_0805_2012Metric_Pad1.18x1.45mm_HandSolder | 2
C7,C19,C20,C23,C31,C32,C33,C35,C38,C39,C40,C41,C42,C43,C44,C45,C46,C47,C48,C49,C50,C51,C52,C53,C54,C55 | 100nF | ~ | Capacitor_SMD:C_0805_2012Metric_Pad1.18x1.45mm_HandSolder | 26
C8,C18,C28,C29 | 12pF | ~ | Capacitor_SMD:C_0805_2012Metric_Pad1.18x1.45mm_HandSolder | 4
C10,C37 | 1uF | ~ | Capacitor_SMD:C_0805_2012Metric_Pad1.18x1.45mm_HandSolder | 2
C11,C15,C56 | 0.1uF | ~ | Capacitor_SMD:C_0805_2012Metric_Pad1.18x1.45mm_HandSolder | 3
C21 | 0.8pF | ~ | Capacitor_SMD:C_0805_2012Metric_Pad1.18x1.45mm_HandSolder | 1
C24 | 1.5p | ~ | Capacitor_SMD:C_0805_2012Metric_Pad1.18x1.45mm_HandSolder | 1
C25 | 1pF | ~ | Capacitor_SMD:C_0805_2012Metric_Pad1.18x1.45mm_HandSolder | 1
C26 | 2.2pF | ~ | Capacitor_SMD:C_0805_2012Metric_Pad1.18x1.45mm_HandSolder | 1
C27 | 2.2nF | ~ | Capacitor_SMD:C_0805_2012Metric_Pad1.18x1.45mm_HandSolder | 1
C30 | 47nF | ~ | Capacitor_SMD:C_0805_2012Metric_Pad1.18x1.45mm_HandSolder | 1
C34 | 1nF | ~ | Capacitor_SMD:C_0805_2012Metric_Pad1.18x1.45mm_HandSolder | 1
C36 | 100nF/NC | ~ | Capacitor_SMD:C_0805_2012Metric_Pad1.18x1.45mm_HandSolder | 1
C57 | 1.5pF | ~ | Capacitor_SMD:C_0805_2012Metric_Pad1.18x1.45mm_HandSolder | 1
D1,D2,D3,D5,D6,D7,D14,D15,D16,D20,D21,D22,D26,D27,D28,D33,D34,D35 | 1N4148 | http://www.vishay.com/docs/88526/1n5820.pdf | canadian_footprints:D_SOD123_axial-dual | 18
D4 | green | ~ | LED_SMD:LED_0805_2012Metric_Pad1.15x1.40mm_HandSolder | 1
D8,D9,D10,D11,D12,D13,D17,D18,D19,D23,D24,D25,D29,D30,D31,D36,D37,D38 | WS2812B | https://cdn-shop.adafruit.com/product-files/4684/4684_WS2812B-2020_V1.3_EN.pdf | LED_SMD:LED_WS2812B-2020_PLCC4_2.0x2.0mm | 18
D32 | red | ~ | LED_SMD:LED_0805_2012Metric_Pad1.15x1.40mm_HandSolder | 1
FB1,FB2 | 60R@100Mhz | ~ | Inductor_SMD:L_0603_1608Metric_Pad1.05x0.95mm_HandSolder | 2
FID1,FID2,FID3,FID4,FID5,FID6,FID7,FID8,FID9 | Fiducial | ~ | Fiducial:Fiducial_1mm_Mask3mm | 9
H1,H2,H3,H4,H5,H6,H7 | MountingHole_Pad | ~ | MountingHole:MountingHole_3.2mm_M3_DIN965_Pad | 7
J1,J5 | SIDE_CON | https://www.usb.org/sites/default/files/documents/usb_type-c.zip | Connector_USB:USB_C_Receptacle_GCT_USB4125-xx-x-0190_6P_TopMnt_Horizontal | 2
J2 | SWD_JLINK | ~ | Connector_PinHeader_2.54mm:PinHeader_1x04_P2.54mm_Horizontal | 1
J3 | 0.91 OLED | ~ | Connector_PinHeader_2.54mm:PinHeader_1x04_P2.54mm_Vertical | 1
J4 | BatCon | ~ | Connector_PinHeader_2.54mm:PinHeader_1x02_P2.54mm_Horizontal | 1
J6 | USB_A | ~ | Connector_USB:USB_A_CNCTech_1001-011-01101_Horizontal | 1
J7 | AVR-ISP-6 | ~ | Connector_PinHeader_2.54mm:PinHeader_2x05_P2.54mm_Vertical | 1
K1,K2,K3,K4,K5,K6,K7,K8,K9,K10,K11,K12,K13,K14,K15,K16,K17,K18 | KEYSW |  | keyswitches.pretty-master:Kailh_socket_MX_optional_reversible_platemount | 18
L1,L2 | 22uH | ~ | Inductor_SMD:L_0603_1608Metric_Pad1.05x0.95mm_HandSolder | 2
L3 | 3.9nH | ~ | Inductor_SMD:L_0603_1608Metric_Pad1.05x0.95mm_HandSolder | 1
L4 | 3.3nH | ~ | Inductor_SMD:L_0603_1608Metric_Pad1.05x0.95mm_HandSolder | 1
L5 | 10nH | ~ | Inductor_SMD:L_0603_1608Metric_Pad1.05x0.95mm_HandSolder | 1
L6 | 4.7nH | ~ | Inductor_SMD:L_0603_1608Metric_Pad1.05x0.95mm_HandSolder | 1
P1 | USB_C_Plug_USB2.0 | https://www.usb.org/sites/default/files/documents/usb_type-c.zip | Connector_USB:USB_C_Receptacle_GCT_USB4105-xx-A_16P_TopMnt_Horizontal | 1
Q1 | PJA3404_(G1,D3,S2) | https://ngspice.sourceforge.io/docs/ngspice-html-manual/manual.xhtml#cha_MOSFETs | Package_TO_SOT_SMD:SOT-23 | 1
Q2 | PJA3405_(G1,D3,S2) | https://ngspice.sourceforge.io/docs/ngspice-html-manual/manual.xhtml#cha_MOSFETs | Package_TO_SOT_SMD:SOT-23 | 1
R1,R2 | 4K7 | ~ | Resistor_SMD:R_0805_2012Metric_Pad1.20x1.40mm_HandSolder | 2
R3,R4 | 5K1 | ~ | Resistor_SMD:R_0805_2012Metric_Pad1.20x1.40mm_HandSolder | 2
R5,R12 | 100k | ~ | Resistor_SMD:R_0805_2012Metric_Pad1.20x1.40mm_HandSolder | 2
R6 | 46.4K | ~ | Resistor_SMD:R_0805_2012Metric_Pad1.20x1.40mm_HandSolder | 1
R7 | 1.18k | ~ | Resistor_SMD:R_0805_2012Metric_Pad1.20x1.40mm_HandSolder | 1
R8,R9,R10,R15,R17 | 1K | ~ | Resistor_SMD:R_0805_2012Metric_Pad1.20x1.40mm_HandSolder | 5
R11 | 1k | ~ | Resistor_SMD:R_0805_2012Metric_Pad1.20x1.40mm_HandSolder | 1
R13,R16 | 100 | ~ | Resistor_SMD:R_0805_2012Metric_Pad1.20x1.40mm_HandSolder | 2
R14 | 1.13k | ~ | Resistor_SMD:R_0805_2012Metric_Pad1.20x1.40mm_HandSolder | 1
SW1 | RST | ~ | Button_Switch_SMD:SW_Push_1P1T_NO_6x6mm_H9.5mm | 1
SW2 | RCV_RST | ~ | Button_Switch_SMD:SW_Push_1P1T_NO_6x6mm_H9.5mm | 1
SW3 | PWR_SWITCH | ~ | Button_Switch_SMD:SW_SPDT_PCM12 | 1
SW4 | 5V_EN | ~ | Button_Switch_SMD:SW_SPDT_PCM12 | 1
TP1 | 0 | ~ | TestPoint:TestPoint_Pad_D1.0mm | 1
TP2 | 1 | ~ | TestPoint:TestPoint_Pad_D1.0mm | 1
TP3 | 2 | ~ | TestPoint:TestPoint_Pad_D1.0mm | 1
TP4 | 3 | ~ | TestPoint:TestPoint_Pad_D1.0mm | 1
TP5 | 4 | ~ | TestPoint:TestPoint_Pad_D1.0mm | 1
TP6 | 5 | ~ | TestPoint:TestPoint_Pad_D1.0mm | 1
TP7 | 19 | ~ | TestPoint:TestPoint_Pad_D1.0mm | 1
TP8 | 20 | ~ | TestPoint:TestPoint_Pad_D1.0mm | 1
TP9 | 22 | ~ | TestPoint:TestPoint_Pad_D1.0mm | 1
TP10 | 23 | ~ | TestPoint:TestPoint_Pad_D1.0mm | 1
TP11 | 24 | ~ | TestPoint:TestPoint_Pad_D1.0mm | 1
TP12 | 25 | ~ | TestPoint:TestPoint_Pad_D1.0mm | 1
TP13 | 26 | ~ | TestPoint:TestPoint_Pad_D1.0mm | 1
TP14 | 27 | ~ | TestPoint:TestPoint_Pad_D1.0mm | 1
TP15 | 28 | ~ | TestPoint:TestPoint_Pad_D1.0mm | 1
TP16 | 29 | ~ | TestPoint:TestPoint_Pad_D1.0mm | 1
TP17 | 30 | ~ | TestPoint:TestPoint_Pad_D1.0mm | 1
TP18 | 31 | ~ | TestPoint:TestPoint_Pad_D1.0mm | 1
U1 | AMS1117-3.3 | http://www.advanced-monolithic.com/pdf/ds1117.pdf | Package_TO_SOT_SMD:SOT-223-3_TabPin2 | 1
U2 | ATmega8U2-A | http://ww1.microchip.com/downloads/en/DeviceDoc/doc7799.pdf | Package_QFP:TQFP-32_7x7mm_P0.8mm | 1
U3 | nRF51x22-QFxx | http://infocenter.nordicsemi.com/pdf/nRF51822_PS_v3.3.pdf | Package_DFN_QFN:QFN-48-1EP_6x6mm_P0.4mm_EP4.6x4.6mm | 1
U4 | CH340C | https://datasheet.lcsc.com/szlcsc/Jiangsu-Qin-Heng-CH340C_C84681.pdf | Package_SO:SOIC-16_3.9x9.9mm_P1.27mm | 1
U5 | BQ24075RGT_DPPM | http://www.ti.com/lit/ds/symlink/bq24075.pdf | Package_DFN_QFN:VQFN-16-1EP_3x3mm_P0.5mm_EP1.6x1.6mm | 1
U6 | TPS63002_SEPIC_5V | http://www.ti.com/lit/ds/symlink/tps63000.pdf | Package_SON:Texas_DRC0010J_ThermalVias | 1
U7 | nRF52832-QFxx | http://infocenter.nordicsemi.com/pdf/nRF52832_PS_v1.4.pdf | Package_DFN_QFN:QFN-48-1EP_6x6mm_P0.4mm_EP4.6x4.6mm | 1
U8 | MCP23017_SS | http://ww1.microchip.com/downloads/en/DeviceDoc/20001952C.pdf | Package_SO:SSOP-28_5.3x10.2mm_P0.65mm | 1
U9 | TPS63001_SEPIC_3V3 | http://www.ti.com/lit/ds/symlink/tps63000.pdf | Package_SON:Texas_DRC0010J_ThermalVias | 1
U10 | MAX17048 | https://datasheets.maximintegrated.com/en/ds/MAX17048-MAX17049.pdf | Package_DFN_QFN:DFN-8-1EP_2x2mm_P0.5mm_EP0.8x1.6mm | 1
Y1 | 32MHz_CF4032M00020001 | ~ | Crystal:Crystal_SMD_2016-4Pin_2.0x1.6mm | 1
Y2 | 8MHz | ~ | Crystal:Crystal_HC50_Vertical | 1
Y3 | 16MHz | ~ | Crystal:Crystal_HC50_Vertical | 1

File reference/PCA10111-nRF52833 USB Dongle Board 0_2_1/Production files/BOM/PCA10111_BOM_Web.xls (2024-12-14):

Bill of material
Board: | PCA10111
Version: | 0.2.1
Designator | Value | Description | Assembly | Footprint Doc | Manufacturer | Manufacturer Part Number
C1, C2, C15, C16 | 12pF | Capacitor, NP0, ±2% |  | 0201 | N.A. | N.A.
C3 | 1.0pF | Capacitor, NP0, ±0.05pF, 50V |  | 0201 | N.A. | N.A.
C4 | 1.2pF | Capacitor, C0G, ±0.1pF, 50V |  | 0201 | N.A. | N.A.
C5, C7, C11, C22, C24, C27 | 100nF | Capacitor, X5R, ±10% |  | 0201 | N.A. | N.A.
C6, C19 | 4.7µF | Capacitor, X7R, ±10%, 6.3V |  | 0603 | Samsung Electro-Mechanics America | CL10B475KQ8NQNC
C8 | 820pF | Capacitor, X7R, ±10% |  | 0201 | N.A. | N.A.
C9, C25 | N.C. | Not mounted | Not mounted | 0201 | N.A. | N.A.
C10 | 100pF | Capacitor, NP0, ±2%, 25V |  | 0201 | Murata | GRM0335C1E101GA01
C12, C13 | 1.0µF | Capacitor, X5R, ±5%, 6.3V |  | 0402 | N.A. | N.A.
C14 | 47nF | Capacitor, X5R, ±10% |  | 0201 | N.A. | N.A.
C17 | 4.7µF | Capacitor, X7S, ±10%, 10V |  | 0603 | N.A. | N.A.
C21 | 10nF | Capacitor, X7R, ±10% |  | 0201 | N.A. | N.A.
C23 | 4.7µF | Capacitor, X5R, ±20% |  | 0402 | N.A. | N.A.
C26 | 1.7pF | Chip Cap 0201 |  | 0201 | N.A. | N.A.
D1 | PRTR5V0U2X | Ultra low capacitance double rail-to-rail ESD protection diode |  | SOT-143B | NXP Semiconductors | PRTR5V0U2X
FB1, FB2 | 120R/0.85A | Ferrite Bead, 120 Ohm @ 100MHz, 850mA, 150 mOhm Max |  | 0201 | Taiyo Yuden | BKP0603HS121-T
L1 | 4.7nH | Inductor, 350mA, ±3% |  | 0201 | Murata | LQP03TN4N7H02D
L2 | 2.2nH | Chip Inductor |  | 0201 | N.A. | N.A.
L3 | 10µH | Inductor, 250mA, ±20%, 1.05ohm. -55°C ~ 125°C |  | 0603 | TDK Corporation | MLZ1608M100WTD25
L4 | 15nH | Inductor, 320mA, ±5% |  | 0402 | Taiyo Yuden | HK100515NJ-T
L5 | 2.7nH | Chip Inductor |  | 0201 | N.A. | N.A.
LD1 | L0603G | LED, Green, 0603, 573nm, Vf=2.0V, 24mcd, - 40 to +85°C |  | 0603 | Victory Electronics | VS 25C7M5
LD2 | LED RGB | RGB LED 1.60 mm x 0.80 mm SMD |  | LED_RGB_0603 | Kingbright Company LLC | APHF1608LSEEQBDZGKC
P1 | Pin Header 2x5, 1.27mm | Pin Header 2x5, 1.27mm (50mil), SMD, Keying Shroud | Not mounted | HDR_2x5-SMD-1.27mm | W-CON | 3132-10MS0BK00R1
R2 | 10k | Resistor, ±1%, 0.05W |  | 0201 | N.A. | N.A.
R3 | 220R | Resistor, ±1%, 0.05W |  | 0201 | N.A. | N.A.
R4 | 1k2 | Resistor, ±1%, 0.05W |  | 0201 | N.A. | N.A.
R5 | 2k2 | Resistor, ±1%, 0.05W |  | 0201 | N.A. | N.A.
R6 | 390R | Resistor, ±1%, 0.05W |  | 0201 | N.A. | N.A.
SW1 | PB SW | Tactile Switch, SPNO, SMD, 260gf, 4.2x3.2x2.5mm |  | PTS810 | C&K | PTS810 SJK 250 SMTR LFS
SW2 | PTS840 GK SMTR LFS | Microminiature SMT Switch, Side Actuated |  | PTS840 Gx | C&K | PTS840 GK SMTR LFS
U1 | nRF52833-QDAA | Multi-protocol Bluetooth Low Energy, IEEE 802.15.4, ANT and 2.4GHz proprietary system-on-chip |  | QFN-40 | Nordic Semiconductor | nRF52833-QDAA
X1 | 32MHz | XTAL SMD 1612, 32MHz, Cl=8pF, Total Tol: ±40ppm |  | XTAL_1612 | N.A. | N.A.
X2 | 32.768kHz | XTAL SMD 2012, 32.768kHz, Cl=9pF, Total Tol: ±50ppm |  | XTAL_2012 | N.A. | N.A.

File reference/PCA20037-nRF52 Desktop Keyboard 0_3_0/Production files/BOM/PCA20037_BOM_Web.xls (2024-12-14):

Bill of material
Board: | PCA20037
Version: | 0.3.0
Designator | Value | Description | Assembly | Footprint Doc | Manufacturer | Manufacturer Part Number
C1, C2, C12, C13 | 12pF | Capacitor, NP0, ±2% |  | 0402
C3 | 0.8pF | Capacitor, NP0, ±5% |  | 0402
C4, C5, C8, C14 | 100nF | Capacitor, X7R, ±10% |  | 0402
C6, C16 | N.C. | Not mounted | Not mounted | 0402
C7 | 100pF | Capacitor, NP0, ±5% |  | 0402
C9 | 4.7µF | Capacitor, X5R, ±10% |  | 0603
C10, C15 | 1.0µF | Capacitor, X7R, ±10% |  | 0603
C11 | 1.2pF | Capacitor, NP0, ±0.1pF |  | 0402
Fiducual1, Fiducual2 |  | Fiducial Mark |  | Fiducial
L1 | 3.9nH | Inductor, 170mA, ±0.1nH |  | 0402 | Murata | LQP15MN3N9B02D
L2 | 10µH | Inductor, 80mA, ±10% |  | 0603 | Taiyo Yuden | LBMF1608T100K
L3 | 15nH | Inductor, 320mA, ±5% |  | 0402 | Taiyo Yuden | HK100515NJ-T
L4 | 1.5nH | Inductor, 280mA, ±0.1nH |  | 0402 | Murata | LQP15MN1N5B02D
LD1 | L0603R | LED 0603, EL19-21SURC |  | 0603 | Everlight | EL-19-21SURC/S530-A2/TR8
P1 | HDR-2, 1mm | 1.0mm pitch connector side entry SMD |  | SM02B-SRSS-TB | JST | SM02B-SRSS-TB(LF)(SN)
P2 | Card Edge, 0.8mm | 0.8mm pitch, dual edge, right angle, SMD, card edge connector |  | 10056847-101LF | FCI | 10056847-101LF
P4 | KBRFBE71_Keyboard_Connector | KBRFBE71 Keyboard Connector |  | KBRFBE71_Keyboard_Connector
R1 | 100R | Resistor, ±1%, 0.063W |  | 0402
SW1 | Switch | SMD slide Switch (ON-ON) |  | JS102011SAQN | C&K Components | JS102011SAQN
U1 | nRF52832-QFAAE0 | Multi-protocol Bluetooth Low Energy, ANT and 2.4GHz proprietary system-on-chip |  | QFN-48 | Nordic Semiconductor | nRF52832-QFAAE0
X1 | 32MHz | XTAL SMD 2016, 32MHz, Cl=8pF, Tol: ±10ppm, Stab: ±20ppm |  | XTAL_2016 | KDS | DSX211G

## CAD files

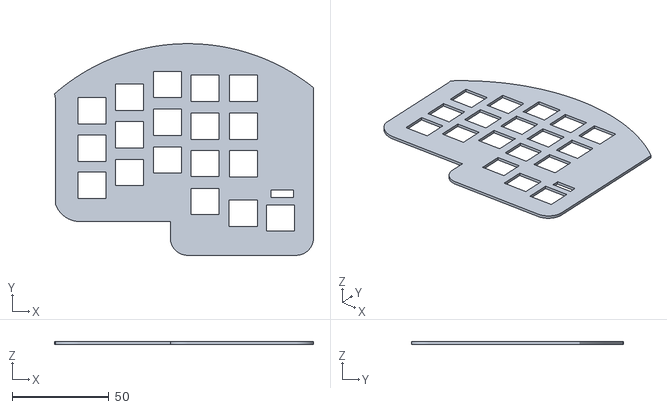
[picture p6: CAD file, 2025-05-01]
casing-design/version2/step/enclosure.stl
133.8 x 109.4 x 1.50

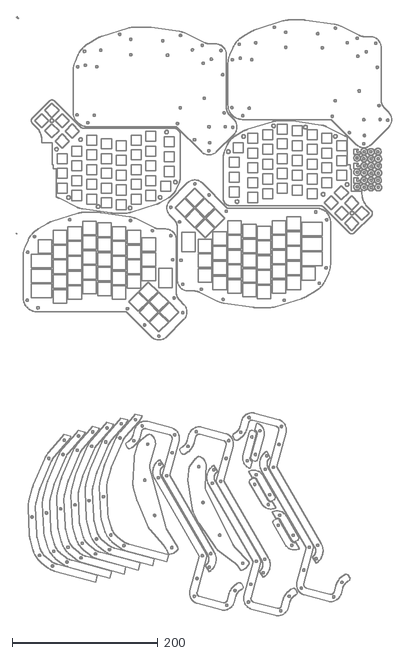
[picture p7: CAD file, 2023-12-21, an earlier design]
casing-design/version1/Export/keyboarddrawing.dxf
515.5 x 823.2

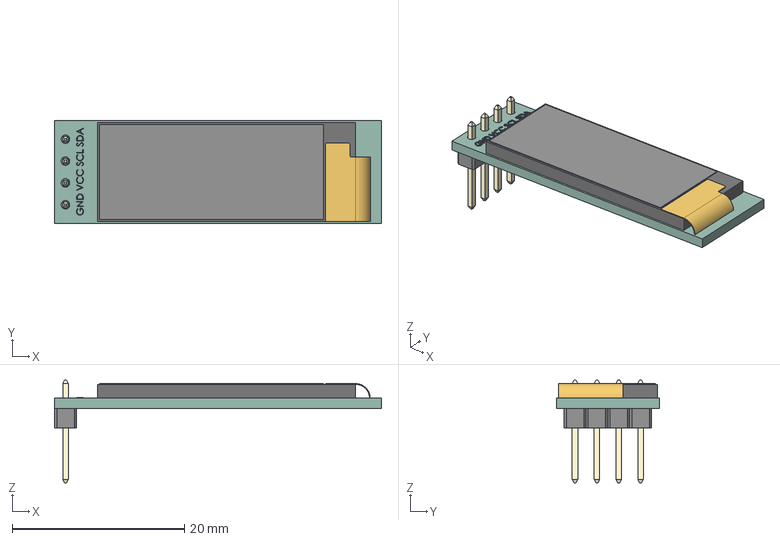
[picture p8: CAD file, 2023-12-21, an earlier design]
casing-design/version1/fromInternet/128x32-OLED.STEP
38.0 x 12.0 x 11.9 mm

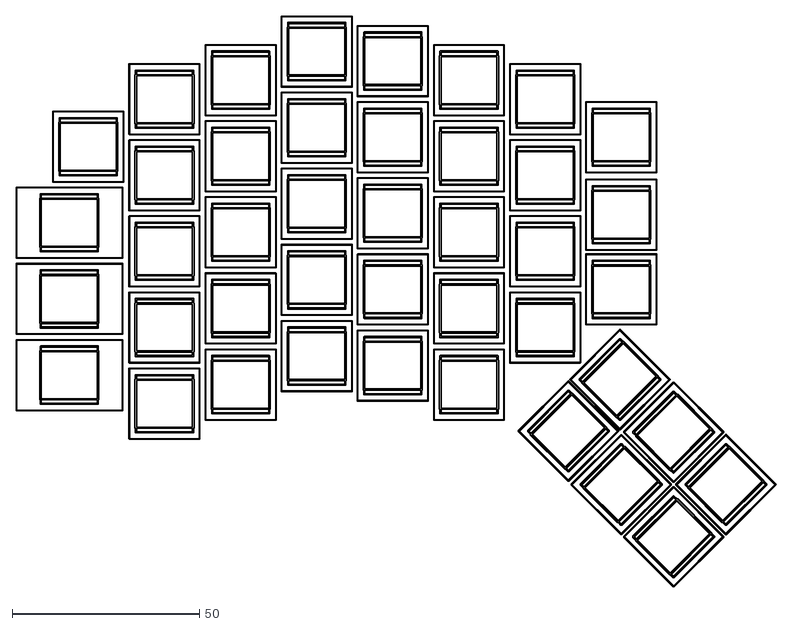
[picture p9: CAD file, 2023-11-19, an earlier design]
pcb-design/version_1/dxf/sudi-redox-clone-User_Drawings.dxf
202.9 x 152.4

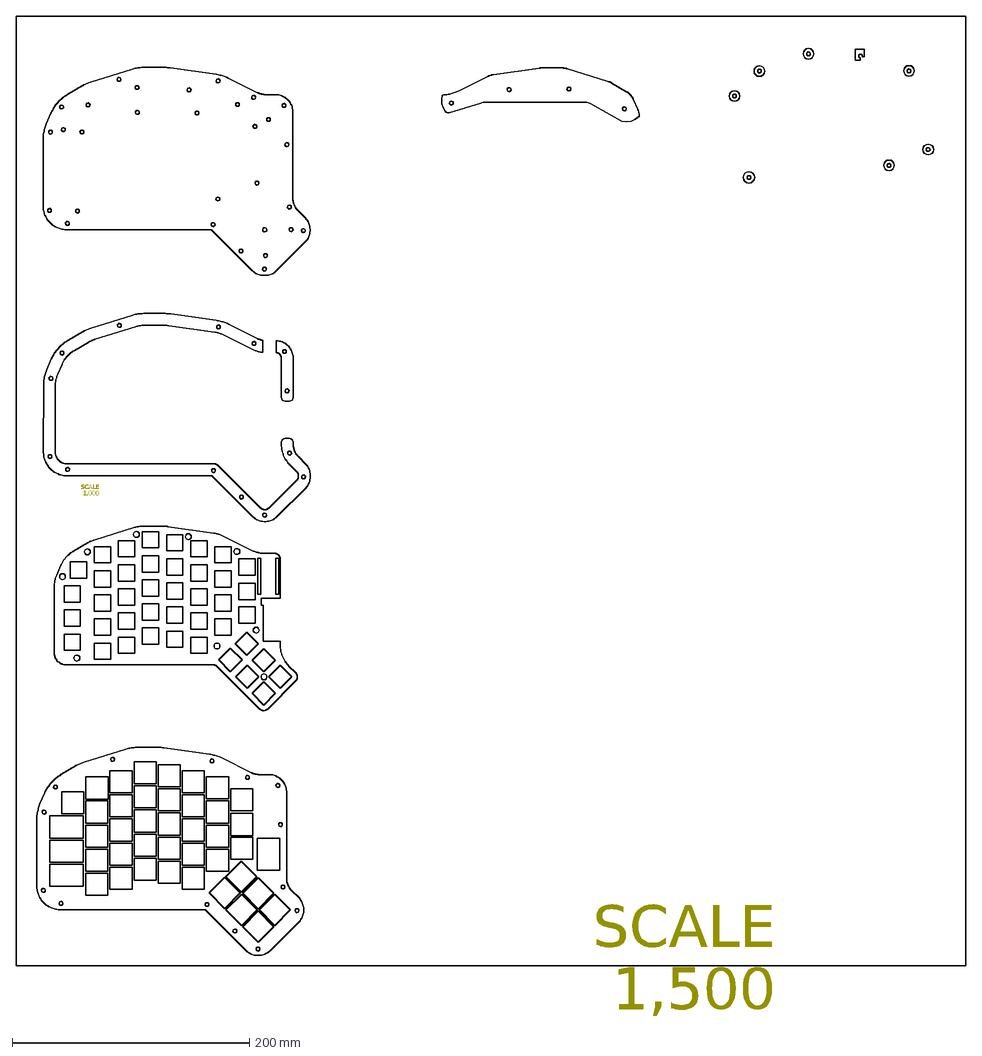
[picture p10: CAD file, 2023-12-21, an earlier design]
casing-design/version1/Export/keyboarddrawing2.dxf
SCALE 1,500
SCALE 1,000

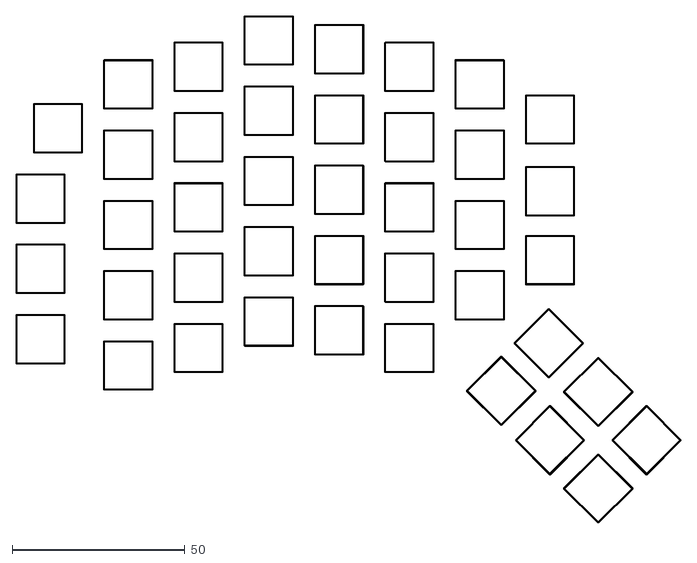
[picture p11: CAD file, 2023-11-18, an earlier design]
pcb-design/version_1/dxf/sudi-redox-clone-User_Eco2.dxf
192.3 x 146.6

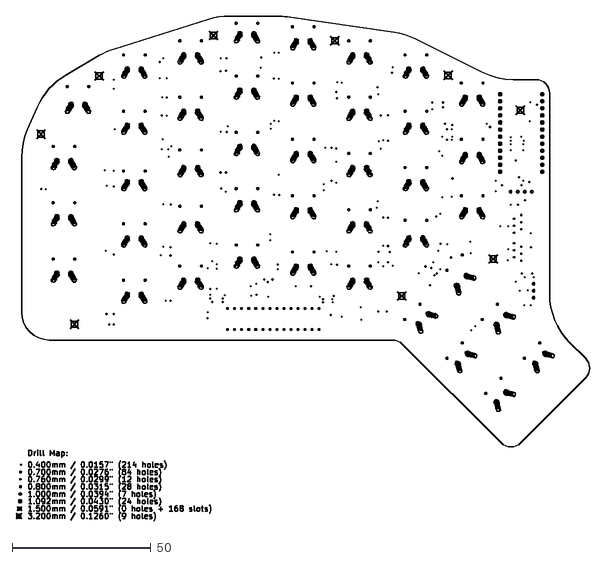
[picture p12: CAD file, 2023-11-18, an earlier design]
pcb-design/version_1/dxf/sudi-redox-clone-PTH-drl_map.dxf
207.5 x 182.1

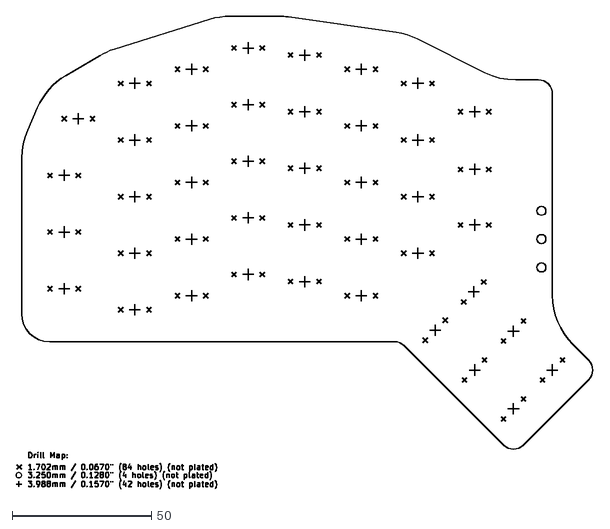
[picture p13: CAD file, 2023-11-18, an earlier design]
pcb-design/version_1/dxf/sudi-redox-clone-NPTH-drl_map.dxf
207.5 x 169.6

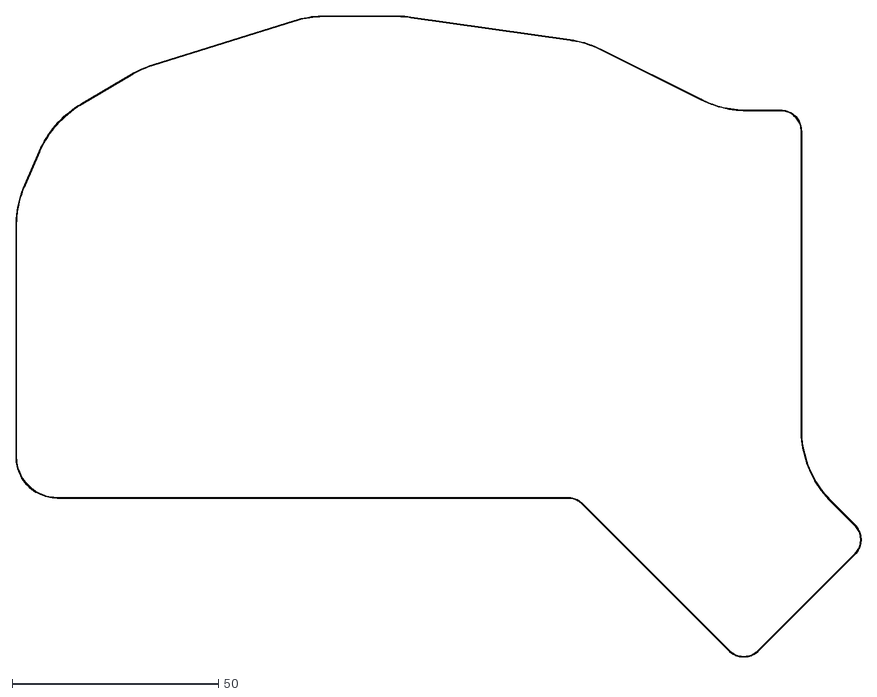
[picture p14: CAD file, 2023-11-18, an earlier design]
pcb-design/version_1/dxf/sudi-redox-clone-Edge_Cuts.dxf
205.0 x 155.5

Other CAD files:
pcb-design/version_1/dxf/sudi-redox-clone-B_Silkscreen.dxf

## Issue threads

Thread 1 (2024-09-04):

Change NRF51 to NRF52832

ahsanu123, 2024-09-04:
- ⚠️  ZMK look not supported NRF51, most of keyboard is use NRF52840, but its not solder friendly.
- ✔️ Most Nearest version for NRF52840 is NRF52832

ahsanu123, 2024-09-04:
changed into nrf52832, Recheck The schematic and pinout usage
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

ahsanu123, 2024-11-20:
done 😄

Closed 2024-11-20.

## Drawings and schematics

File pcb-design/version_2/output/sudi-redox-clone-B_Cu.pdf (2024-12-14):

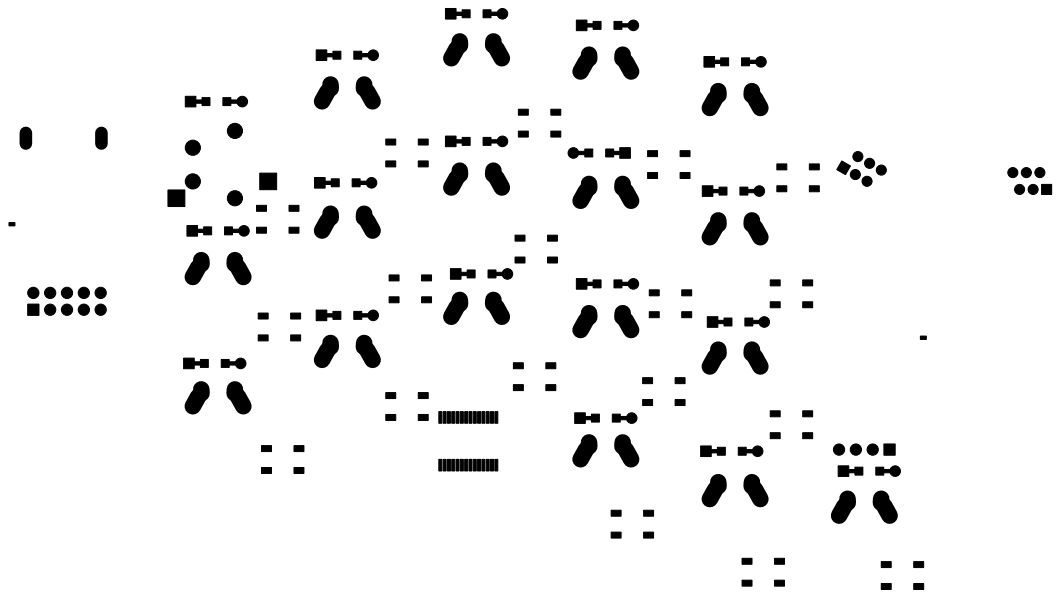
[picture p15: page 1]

File: sudi-redox-clone.kicad_pcb Sheet: AHAH_TERROR

Id: 1/1 Title: SUDI - Split Ergonomic Keyboard

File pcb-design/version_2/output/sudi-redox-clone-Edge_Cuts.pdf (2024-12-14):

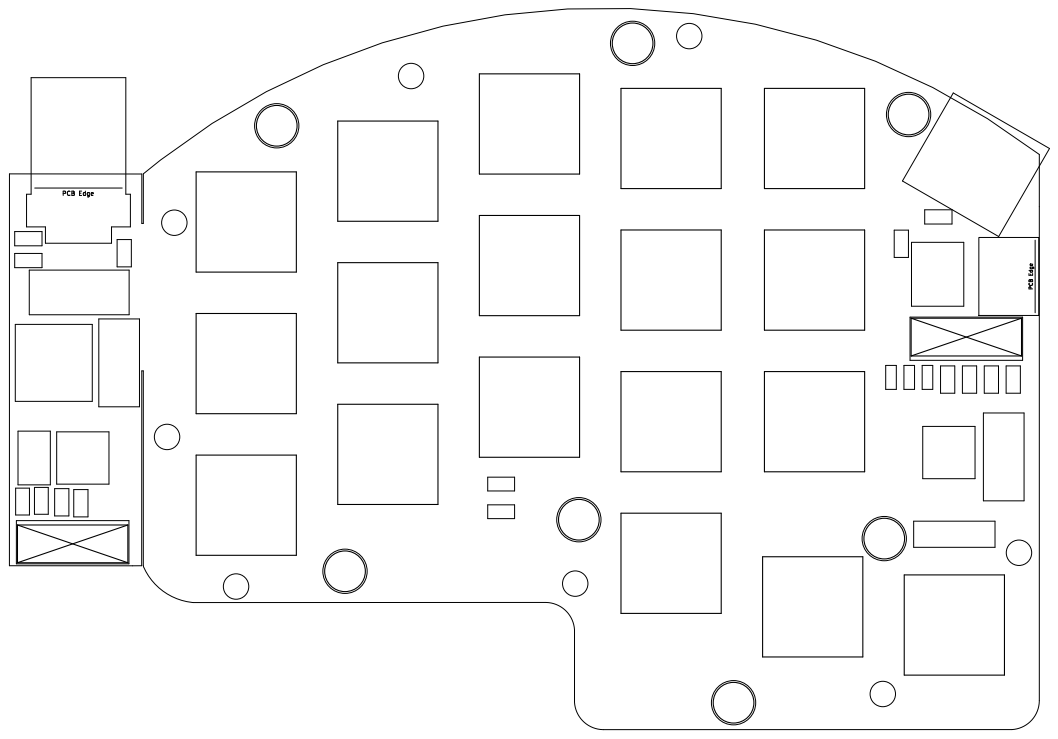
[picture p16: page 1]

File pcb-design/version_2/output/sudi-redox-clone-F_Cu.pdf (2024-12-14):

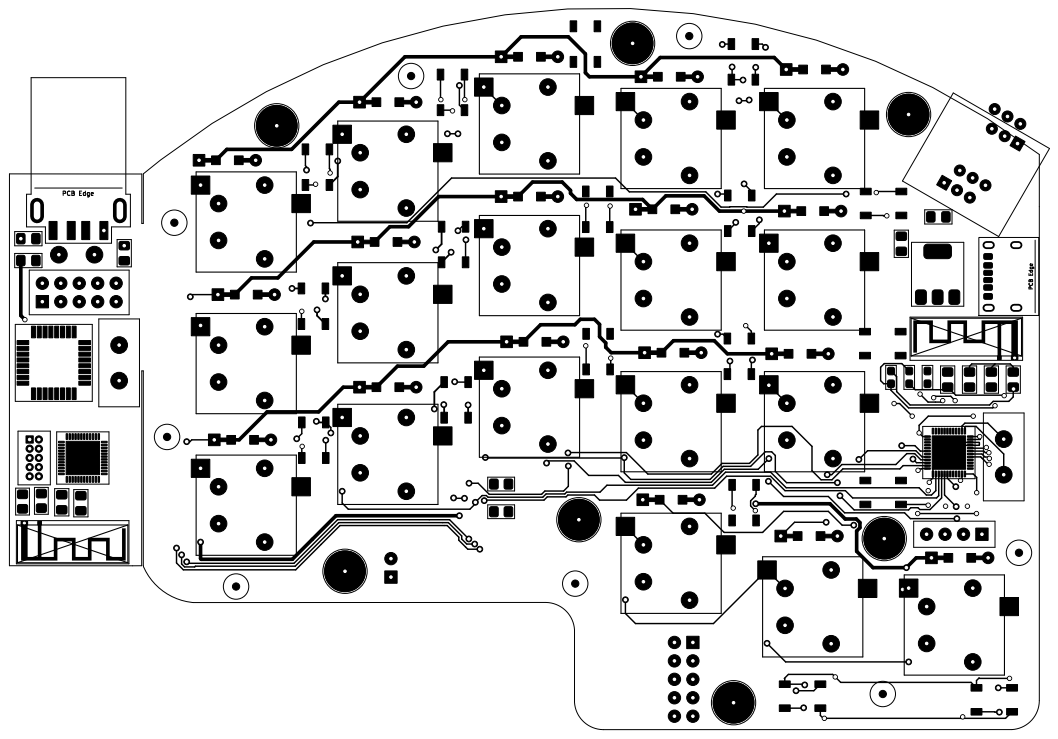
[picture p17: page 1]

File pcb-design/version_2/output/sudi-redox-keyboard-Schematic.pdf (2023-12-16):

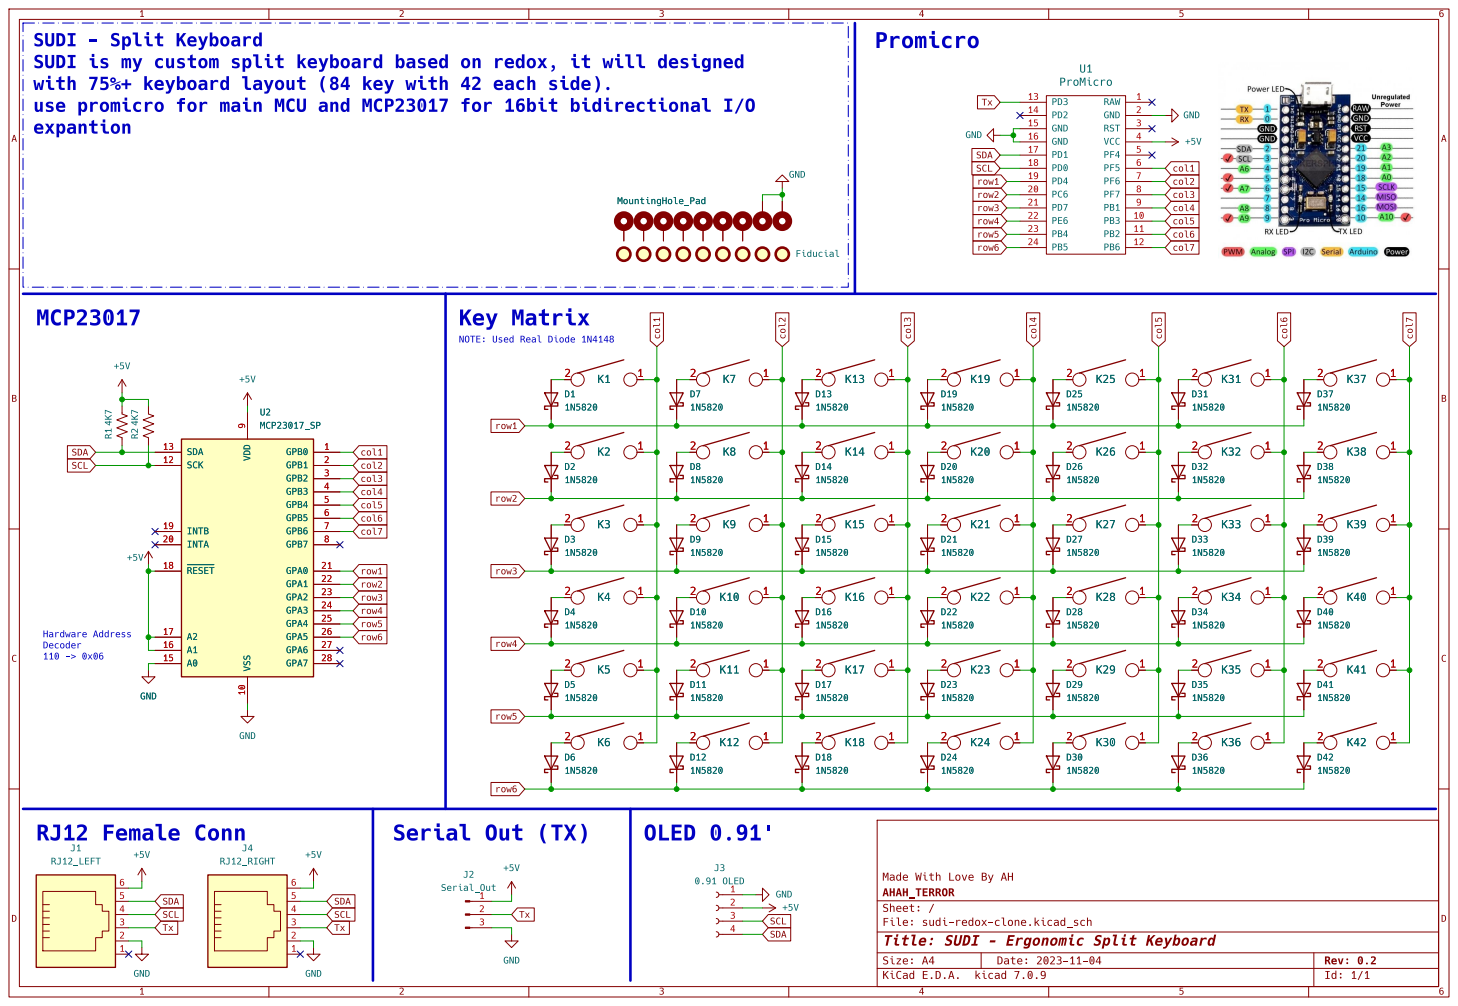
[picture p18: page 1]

with 75%+ keyboard layout (84 key with 42 each side).
expantion

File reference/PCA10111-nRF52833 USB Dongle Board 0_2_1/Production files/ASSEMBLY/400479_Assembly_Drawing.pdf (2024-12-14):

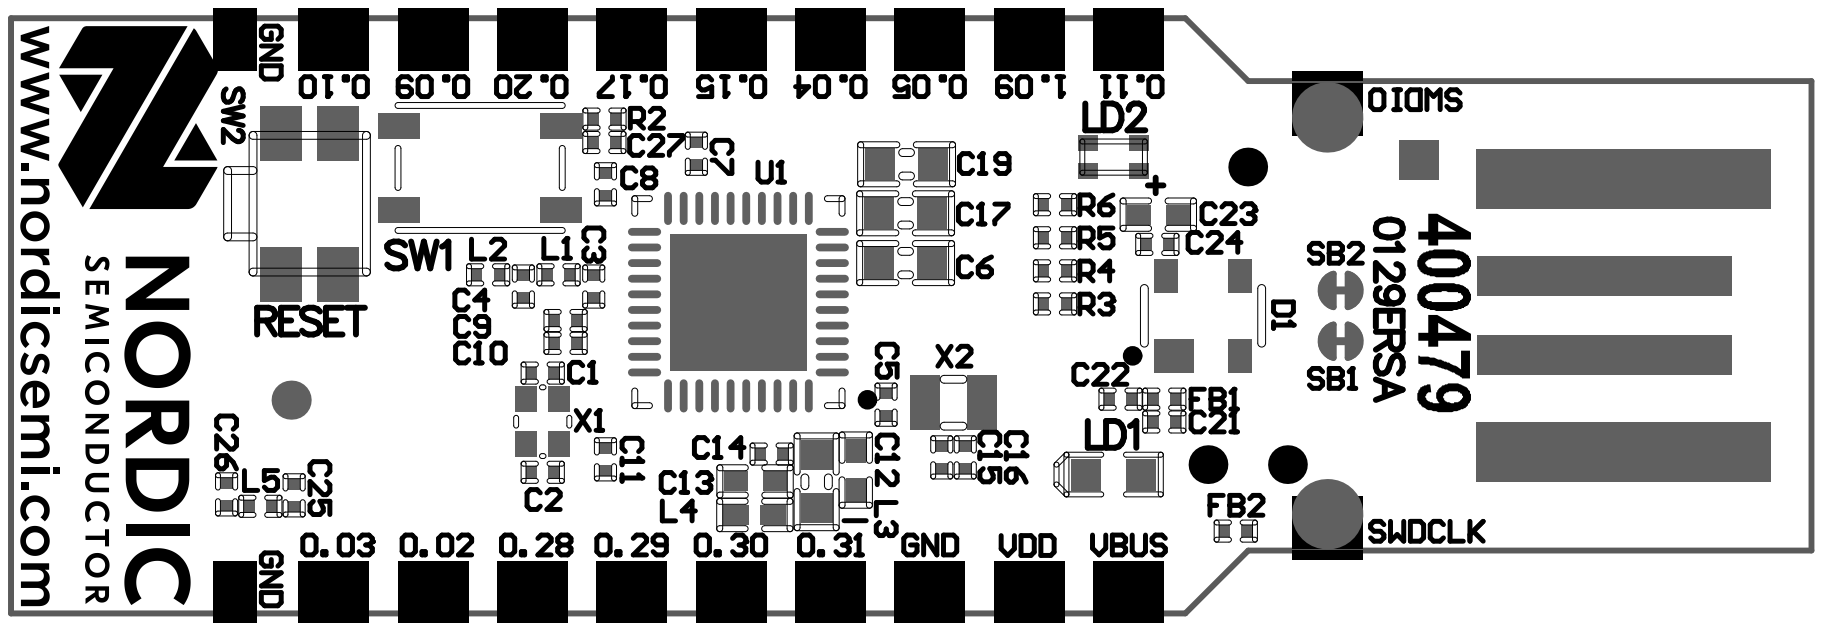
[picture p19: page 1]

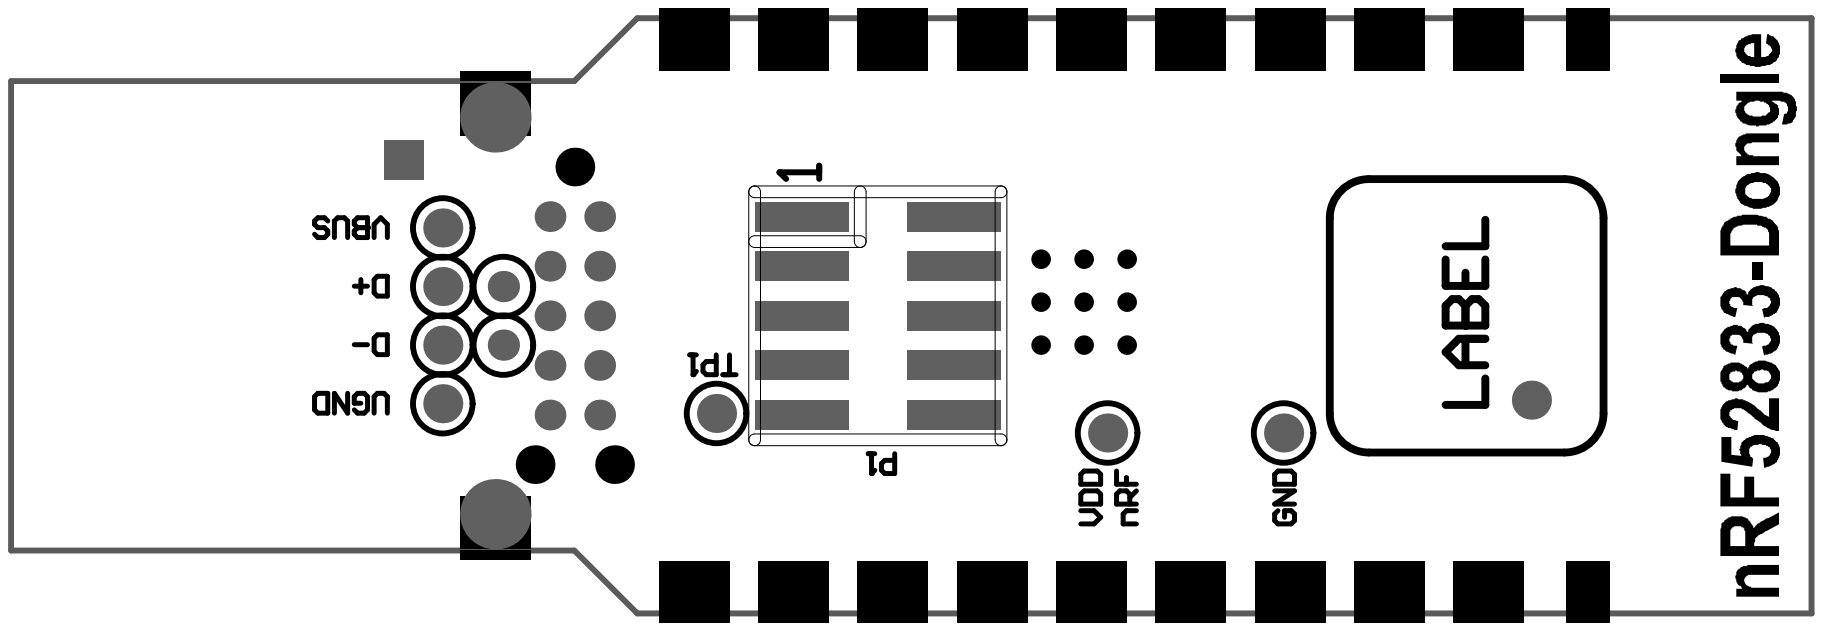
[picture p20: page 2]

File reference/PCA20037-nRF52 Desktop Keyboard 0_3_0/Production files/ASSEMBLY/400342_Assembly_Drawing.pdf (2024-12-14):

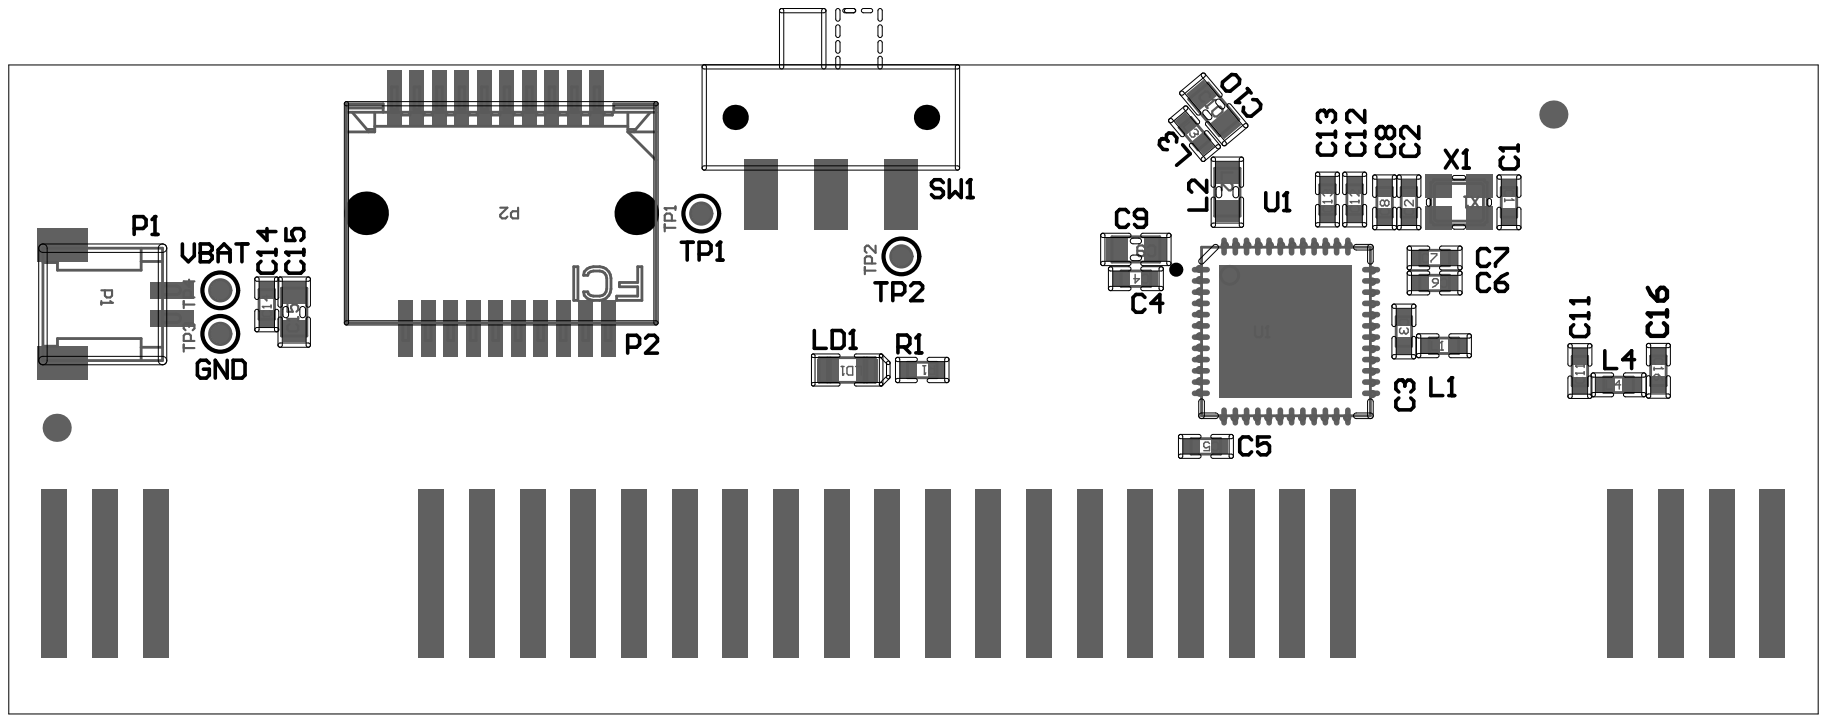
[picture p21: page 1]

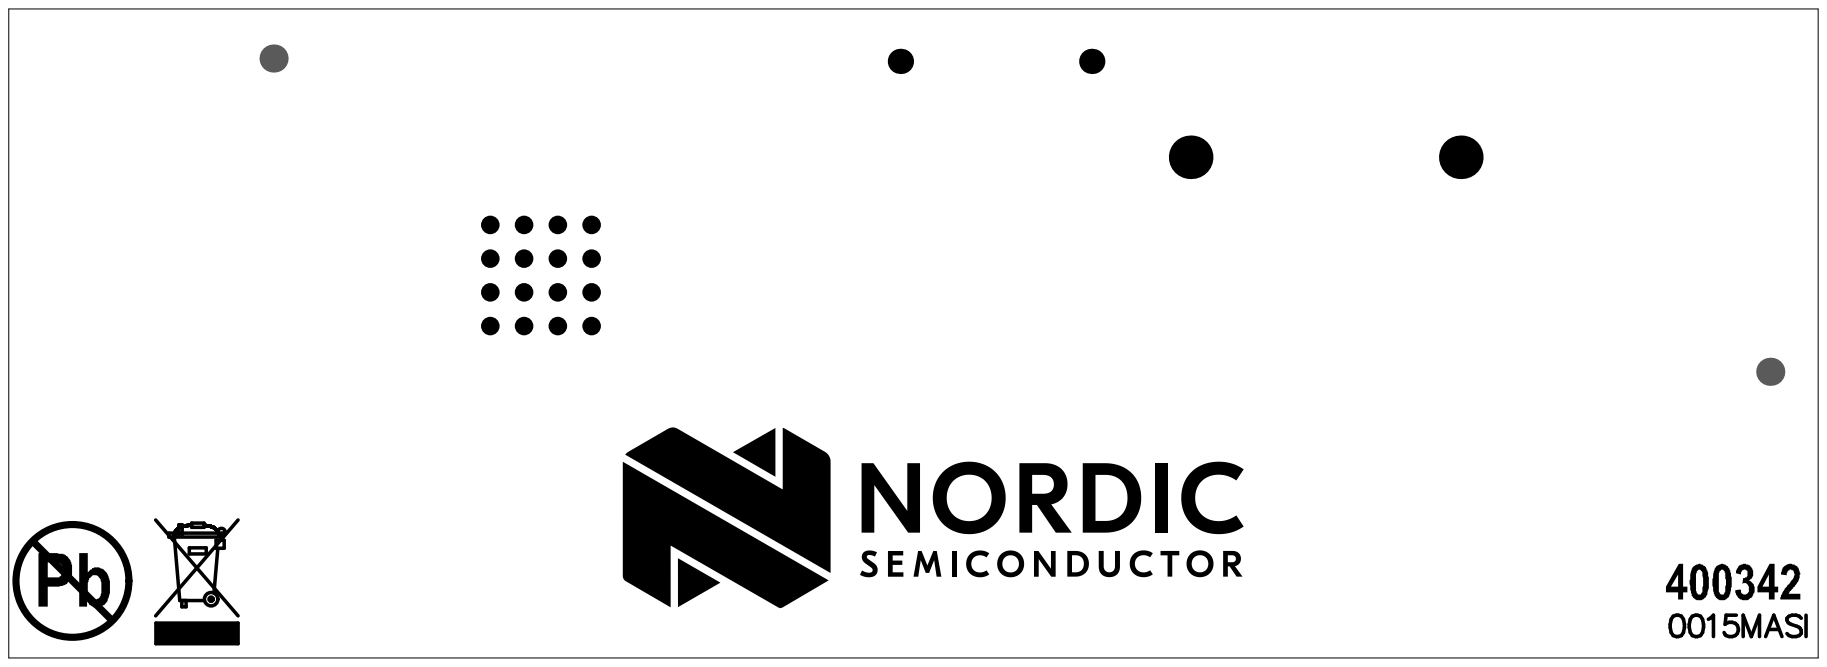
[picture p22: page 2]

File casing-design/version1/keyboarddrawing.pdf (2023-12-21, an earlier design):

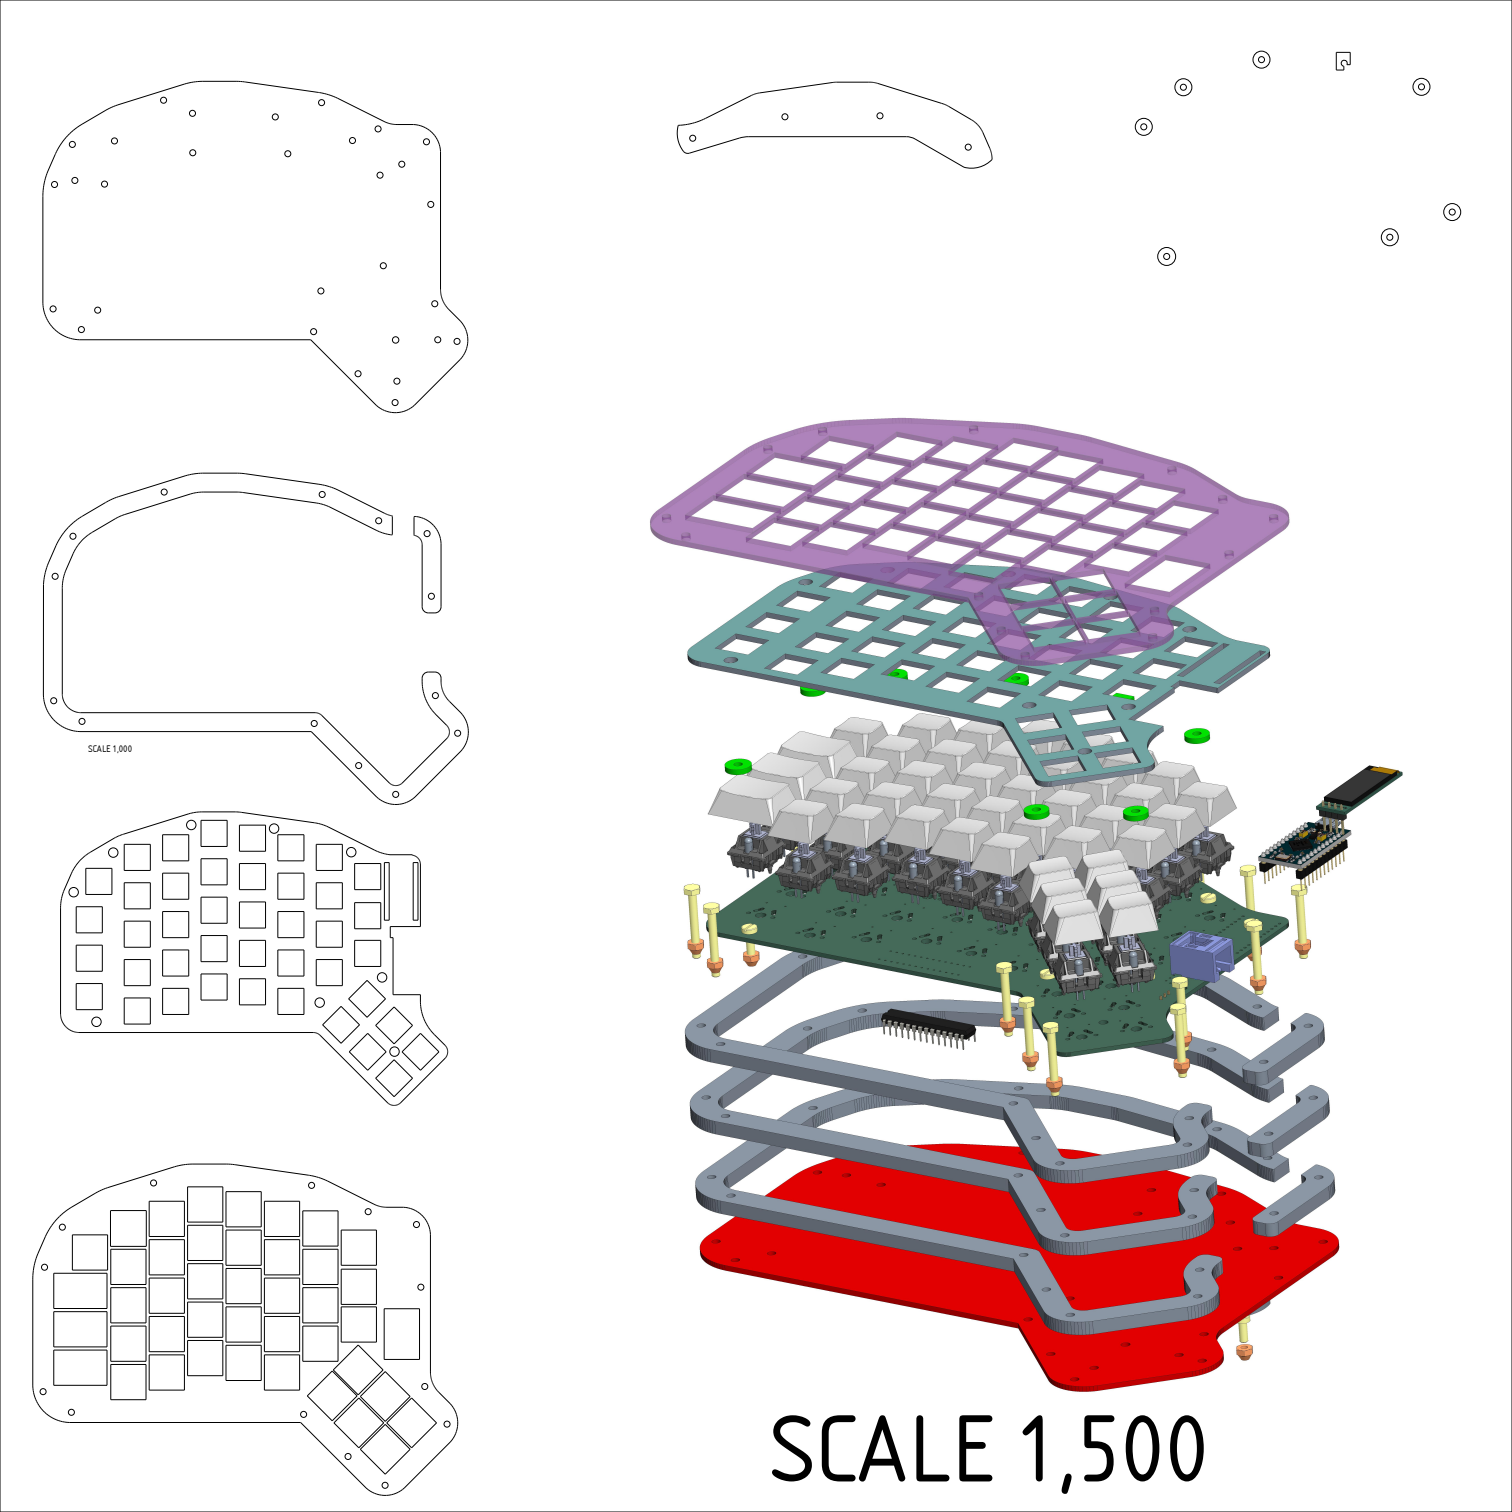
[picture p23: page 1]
SCALE 1,500; SCALE 1,000

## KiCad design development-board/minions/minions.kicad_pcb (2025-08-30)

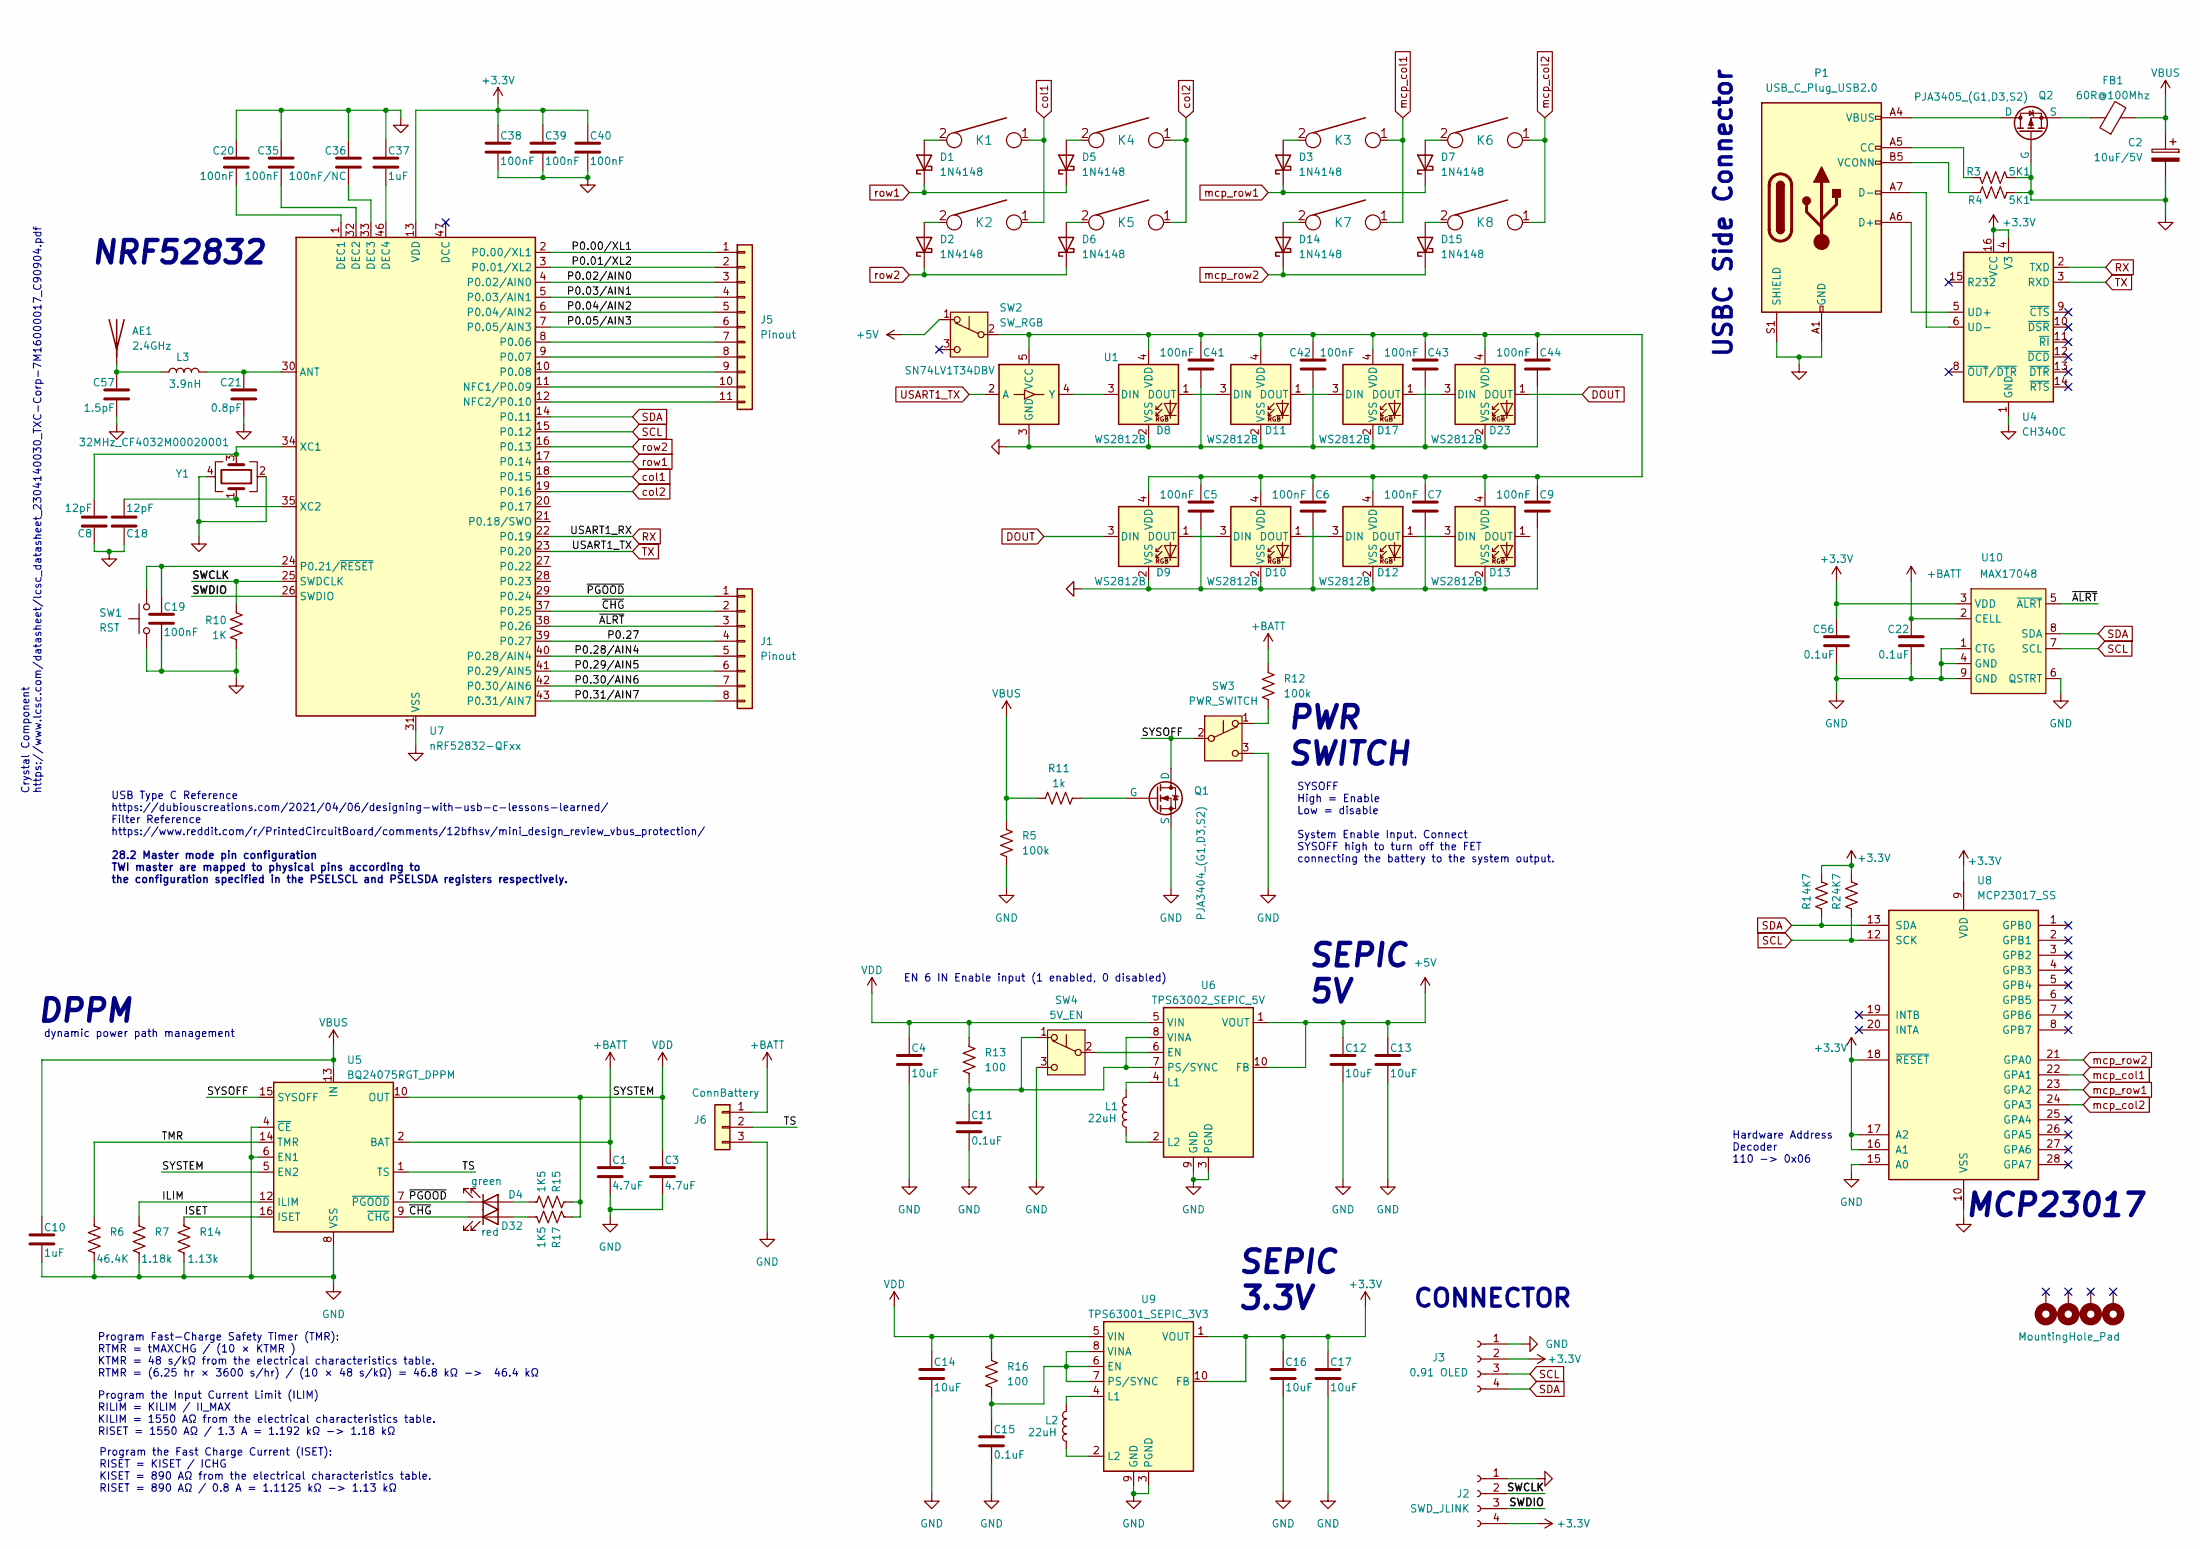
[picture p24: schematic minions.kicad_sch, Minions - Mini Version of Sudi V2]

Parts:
AE1: 2.4GHz; Texas_SWRA117D_2.4GHz_Left
C1, C3: 4.7uF; C_0805_2012Metric_Pad1.18x1.45mm_HandSolder
C2: 10uF/5V; C_0805_2012Metric_Pad1.18x1.45mm_HandSolder
C4, C12, C13, C14, C16, C17: 10uF; C_0805_2012Metric_Pad1.18x1.45mm_HandSolder
C5, C6, C7, C9, C19, C20, C35, C38, C39, C40, C41, C42, C43, C44: 100nF; C_0805_2012Metric_Pad1.18x1.45mm_HandSolder
C8, C18: 12pF; C_0805_2012Metric_Pad1.18x1.45mm_HandSolder
C10, C37: 1uF; C_0805_2012Metric_Pad1.18x1.45mm_HandSolder
C11, C15, C22, C56: 0.1uF; C_0805_2012Metric_Pad1.18x1.45mm_HandSolder
C21: 0.8pF; C_0805_2012Metric_Pad1.18x1.45mm_HandSolder
C36: 100nF/NC; C_0805_2012Metric_Pad1.18x1.45mm_HandSolder
C57: 1.5pF; C_0805_2012Metric_Pad1.18x1.45mm_HandSolder
D1, D2, D3, D5, D6, D7, D14, D15: 1N4148; D_SOD123_axial-dual
D4: green; LED_0805_2012Metric_Pad1.15x1.40mm_HandSolder
D8, D9, D10, D11, D12, D13, D17, D23: WS2812B; LED_WS2812B-2020_PLCC4_2.0x2.0mm
D32: red; LED_0805_2012Metric_Pad1.15x1.40mm_HandSolder
FB1: 60R@100Mhz; L_0603_1608Metric_Pad1.05x0.95mm_HandSolder
H4, H5, H6, H7: MountingHole_Pad; MountingHole_3.2mm_M3_DIN965_Pad
J1: Pinout; PinHeader_1x08_P2.54mm_Vertical
J2: SWD_JLINK; PinHeader_1x04_P2.54mm_Vertical
J3: 0.91 OLED; PinHeader_1x04_P2.54mm_Vertical
J5: Pinout; PinHeader_1x11_P2.54mm_Vertical
J6: ConnBattery; PinHeader_1x03_P2.54mm_Vertical
K1, K2, K3, K4, K5, K6, K7, K8: KEYSW; Kailh_socket_MX_optional_reversible_platemount
L1, L2: 22uH; L_Bourns_SRP7028A_7.3x6.6mm
L3: 3.9nH; L_0603_1608Metric_Pad1.05x0.95mm_HandSolder
P1: USB_C_Plug_USB2.0; USB_C_Receptacle_GCT_USB4110
Q1: PJA3404_(G1,D3,S2); SOT-23
Q2: PJA3405_(G1,D3,S2); SOT-23
R1, R2: 4K7; R_0805_2012Metric_Pad1.20x1.40mm_HandSolder
R3, R4: 5K1; R_0805_2012Metric_Pad1.20x1.40mm_HandSolder
R5, R12: 100k; R_0805_2012Metric_Pad1.20x1.40mm_HandSolder
R6: 46.4K; R_0805_2012Metric_Pad1.20x1.40mm_HandSolder
R7: 1.18k; R_0805_2012Metric_Pad1.20x1.40mm_HandSolder
R10: 1K; R_0805_2012Metric_Pad1.20x1.40mm_HandSolder
R11: 1k; R_0805_2012Metric_Pad1.20x1.40mm_HandSolder
R13, R16: 100; R_0805_2012Metric_Pad1.20x1.40mm_HandSolder
R14: 1.13k; R_0805_2012Metric_Pad1.20x1.40mm_HandSolder
R15, R17: 1K5; R_0805_2012Metric_Pad1.20x1.40mm_HandSolder
SW1: RST; SW_Push_1P1T_NO_6x6mm_H9.5mm
SW2: SW_RGB; SW_SPDT_PCM12
SW3: PWR_SWITCH; SW_SPDT_PCM12
SW4: 5V_EN; SW_SPDT_PCM12
U1: SN74LV1T34DBV; SOT-23-5_HandSoldering
U4: CH340C; SOIC-16_3.9x9.9mm_P1.27mm
U5: BQ24075RGT_DPPM; VQFN-16-1EP_3x3mm_P0.5mm_EP1.6x1.6mm
U6: TPS63002_SEPIC_5V; Texas_DRC0010J_ThermalVias
U7: nRF52832-QFxx; QFN-48-1EP_6x6mm_P0.4mm_EP4.6x4.6mm
U8: MCP23017_SS; SSOP-28_5.3x10.2mm_P0.65mm
U9: TPS63001_SEPIC_3V3; Texas_DRC0010J_ThermalVias
U10: MAX17048; DFN-8-1EP_2x2mm_P0.5mm_EP0.8x1.6mm
Y1: 32MHz_CF4032M00020001; Crystal_SMD_3225-4Pin_3.2x2.5mm_HandSoldering

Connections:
+3.3V: C16.1, C17.1, C38.1, C39.1, C40.1, C56.1, J2.4, J3.2, R1.1, R2.1, U4.4 (V3), U4.16 (VCC), U7.13 (VDD), U7.36 (VDD), U7.48 (VDD), U8.9 (VDD), U8.16 (A1), U8.17 (A2), U8.18 (~RESET), U9.1 (VOUT), U9.10 (FB), U10.3 (VDD)
+5V: C12.1, C13.1, SW2.1 (A), U6.1 (VOUT), U6.10 (FB)
+BATT: C1.1, C22.1, J6.1, R12.1, U5.2 (BAT), U5.3 (BAT), U10.2 (CELL)
/ILIM: R7.1, U5.12 (ILIM)
/ISET: R14.1, U5.16 (ISET)
/P0.00/XL1: J5.1, U7.2 (P0.00/XL1)
/P0.01/XL2: J5.2, U7.3 (P0.01/XL2)
/P0.02/AIN0: J5.3, U7.4 (P0.02/AIN0)
/P0.03/AIN1: J5.4, U7.5 (P0.03/AIN1)
/P0.04/AIN2: J5.5, U7.6 (P0.04/AIN2)
/P0.05/AIN3: J5.6, U7.7 (P0.05/AIN3)
/P0.27: J1.4, U7.39 (P0.27)
/P0.28/AIN4: J1.5, U7.40 (P0.28/AIN4)
/P0.29/AIN5: J1.6, U7.41 (P0.29/AIN5)
/P0.30/AIN6: J1.7, U7.42 (P0.30/AIN6)
/P0.31/AIN7: J1.8, U7.43 (P0.31/AIN7)
/SWCLK: J2.2, R10.2, U7.25 (SWDCLK)
/SWDIO: J2.3, U7.26 (SWDIO)
/SYSOFF: Q1.3 (D), SW3.2 (B), U5.15 (SYSOFF)
/TMR: R6.1, U5.14 (TMR)
/TS: J6.2, U5.1 (TS)
/~ALRT: J1.3, U7.38 (P0.26), U10.5 (~ALRT)
/~CHG: D32.1 (K), J1.2, U5.9 (~CHG), U7.37 (P0.25)
/~PGOOD: D4.1 (K), J1.1, U5.7 (~PGOOD), U7.29 (P0.24)
DOUT: D9.3 (DIN), D23.1 (DOUT)
GND: C1.2, C2.2, C3.2, C4.2, C5.2, C6.2, C7.2, C8.1, C9.2, C10.2, C11.2, C12.2, C13.2, C14.2, C15.2, C16.2, C17.2, C18.1, C19.2, C20.1, C21.2, C22.2, C35.1, C36.1, C37.1, C38.2, C39.2, C40.2, C41.2, C42.2, C43.2, C44.2, C56.2, C57.2, D8.2 (VSS), D9.2 (VSS), D10.2 (VSS), D11.2 (VSS), D12.2 (VSS), D13.2 (VSS), D17.2 (VSS), D23.2 (VSS), J2.1, J3.1, J6.3, P1.A1 (GND), P1.A12 (GND), P1.B1 (GND), P1.B12 (GND), P1.S1 (SHIELD), Q1.2 (S), Q2.1 (G), R3.2, R4.2, R5.2, R6.2, R7.2, R10.1, R14.2, SW1.1, SW3.3 (C), SW4.3 (C), U1.3 (GND), U4.1 (GND), U5.4 (~CE), U5.6 (EN1), U5.8 (VSS), U5.17 (VSS), U6.3 (PGND), U6.9 (GND), U6.11 (PGND), U7.31 (VSS), U7.45 (VSS), U7.49 (VSS), U8.10 (VSS), U8.15 (A0), U9.3 (PGND), U9.9 (GND), U9.11 (PGND), U10.1 (CTG), U10.4 (GND), U10.6 (QSTRT), U10.9 (GND), Y1.2, Y1.4
unnamed: AE1.1 (A), C57.1, L3.1
unnamed: D1.2 (A), K1.2
unnamed: D2.2 (A), K2.2
unnamed: D3.2 (A), K3.2
unnamed: D4.2 (A), R15.1
unnamed: D5.2 (A), K4.2
unnamed: D6.2 (A), K5.2
unnamed: D7.2 (A), K6.2
unnamed: D8.3 (DIN), U1.4 (Y)
unnamed: D9.1 (DOUT), D10.3 (DIN)
unnamed: D10.1 (DOUT), D12.3 (DIN)
unnamed: C5.1, C6.1, C7.1, C9.1, C41.1, C42.1, C43.1, C44.1, D8.4 (VDD), D9.4 (VDD), D10.4 (VDD), D11.4 (VDD), D12.4 (VDD), D13.4 (VDD), D17.4 (VDD), D23.4 (VDD), SW2.2 (B), U1.5 (VCC)
unnamed: D8.1 (DOUT), D11.3 (DIN)
unnamed: D11.1 (DOUT), D17.3 (DIN)
unnamed: D12.1 (DOUT), D13.3 (DIN)
unnamed: D14.2 (A), K7.2
unnamed: D15.2 (A), K8.2
unnamed: D17.1 (DOUT), D23.3 (DIN)
unnamed: D32.2 (A), R17.1
unnamed: J5.7, U7.8 (P0.06)
unnamed: J5.8, U7.9 (P0.07)
unnamed: J5.9, U7.10 (P0.08)
unnamed: J5.10, U7.11 (NFC1/P0.09)
unnamed: J5.11, U7.12 (NFC2/P0.10)
unnamed: P1.A5 (CC), R3.1
unnamed: P1.A6 (D+), U4.5 (UD+)
unnamed: P1.A7 (D-), U4.6 (UD-)
unnamed: P1.B5 (VCONN), R4.1
unnamed: Q1.1 (G), R11.2
unnamed: P1.A4 (VBUS), P1.A9 (VBUS), P1.B4 (VBUS), P1.B9 (VBUS), Q2.3 (D)
unnamed: FB1.1, Q2.2 (S)
unnamed: R12.2, SW3.1 (A)
unnamed: C11.1, R13.2, SW4.1 (A), U6.7 (PS/SYNC), U6.8 (VINA)
unnamed: SW4.2 (B), U6.6 (EN)
unnamed: L1.2, U6.4 (L1)
unnamed: L1.1, U6.2 (L2)
unnamed: C21.1, L3.2, U7.30 (ANT)
unnamed: C20.2, U7.1 (DEC1)
unnamed: C35.2, U7.32 (DEC2)
unnamed: C36.2, U7.33 (DEC3)
unnamed: C37.2, U7.46 (DEC4)
unnamed: C19.1, SW1.2, U7.24 (P0.21/~RESET)
unnamed: C8.2, U7.34 (XC1), Y1.3
unnamed: C18.2, U7.35 (XC2), Y1.1
unnamed: C15.1, R16.2, U9.6 (EN), U9.7 (PS/SYNC), U9.8 (VINA)
unnamed: L2.2, U9.4 (L1)
unnamed: L2.1, U9.2 (L2)
RX: U4.2 (TXD), U7.22 (P0.19)
SCL: J3.3, R2.2, U7.15 (P0.12), U8.12 (SCK), U10.7 (SCL)
SDA: J3.4, R1.2, U7.14 (P0.11), U8.13 (SDA), U10.8 (SDA)
TX: U1.2 (A), U4.3 (RXD), U7.23 (P0.20)
VBUS: C2.1, C10.1, FB1.2, R5.1, R11.1, U5.13 (IN)
VDD: C3.1, C4.1, C14.1, R13.1, R15.2, R16.1, R17.2, U5.5 (EN2), U5.10 (OUT), U5.11 (OUT), U6.5 (VIN), U9.5 (VIN)
col1: K1.1, K2.1, U7.18 (P0.15)
col2: K4.1, K5.1, U7.19 (P0.16)
mcp_col1: K3.1, K7.1, U8.22 (GPA1)
mcp_col2: K6.1, K8.1, U8.24 (GPA3)
mcp_row1: D3.1 (K), D7.1 (K), U8.23 (GPA2)
mcp_row2: D14.1 (K), D15.1 (K), U8.21 (GPA0)
row1: D1.1 (K), D5.1 (K), U7.17 (P0.14)
row2: D2.1 (K), D6.1 (K), U7.16 (P0.13)

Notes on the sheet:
DPPM
EN 6 IN Enable input (1 enabled, 0 disabled)
dynamic power path management
28.2 Master mode pin configuration TWI master are mapped to physical pins according to the configuration specified in the PSELSCL and PSELSDA registers respectively.
SEPIC 5V
USB Type C Reference https://dubiouscreations.com/2021/04/06/designing-with-usb-c-lessons-learned/ Filter Reference https://www.reddit.com/r/PrintedCircuitBoard/comments/12bfhsv/mini_design_review_vbus_protection/
Program the Input Current Limit (ILIM) RILIM = KILIM / II_MAX KILIM = 1550 AΩ from the electrical characteristics table. RISET = 1550 AΩ / 1.3 A = 1.192 kΩ -> 1.18 kΩ
USBC Side Connector
NRF52832
MCP23017
PWR SWITCH
SEPIC 3.3V
Crystal Component https://www.lcsc.com/datasheet/lcsc_datasheet_2304140030_TXC-Corp-7M16000017_C90904.pdf
Program the Fast Charge Current (ISET): RISET = KISET / ICHG KISET = 890 AΩ from the electrical characteristics table. RISET = 890 AΩ / 0.8 A = 1.1125 kΩ -> 1.13 kΩ
CONNECTOR
Hardware Address Decoder 110 -> 0x06
Program Fast-Charge Safety Timer (TMR): RTMR = tMAXCHG / (10 × KTMR ) KTMR = 48 s/kΩ from the electrical characteristics table. RTMR = (6.25 hr × 3600 s/hr) / (10 × 48 s/kΩ) = 46.8 kΩ -> 46.4 kΩ
SYSOFF High = Enable Low = disable System Enable Input. Connect SYSOFF high to turn off the FET connecting the battery to the system output.

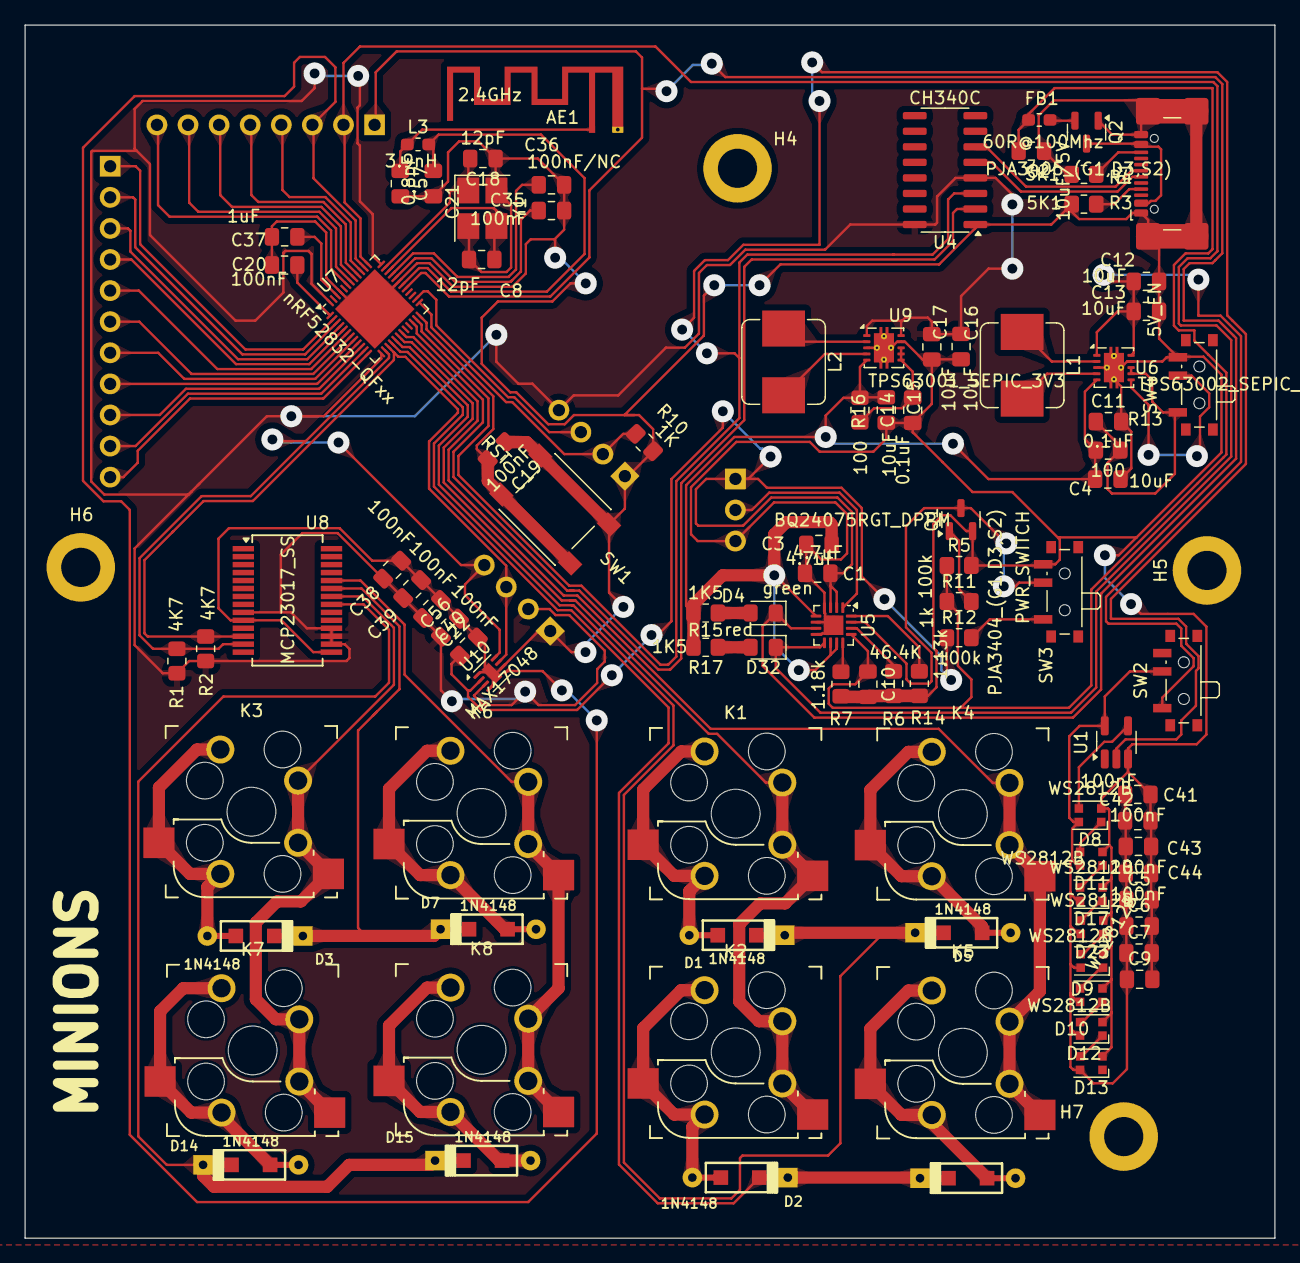
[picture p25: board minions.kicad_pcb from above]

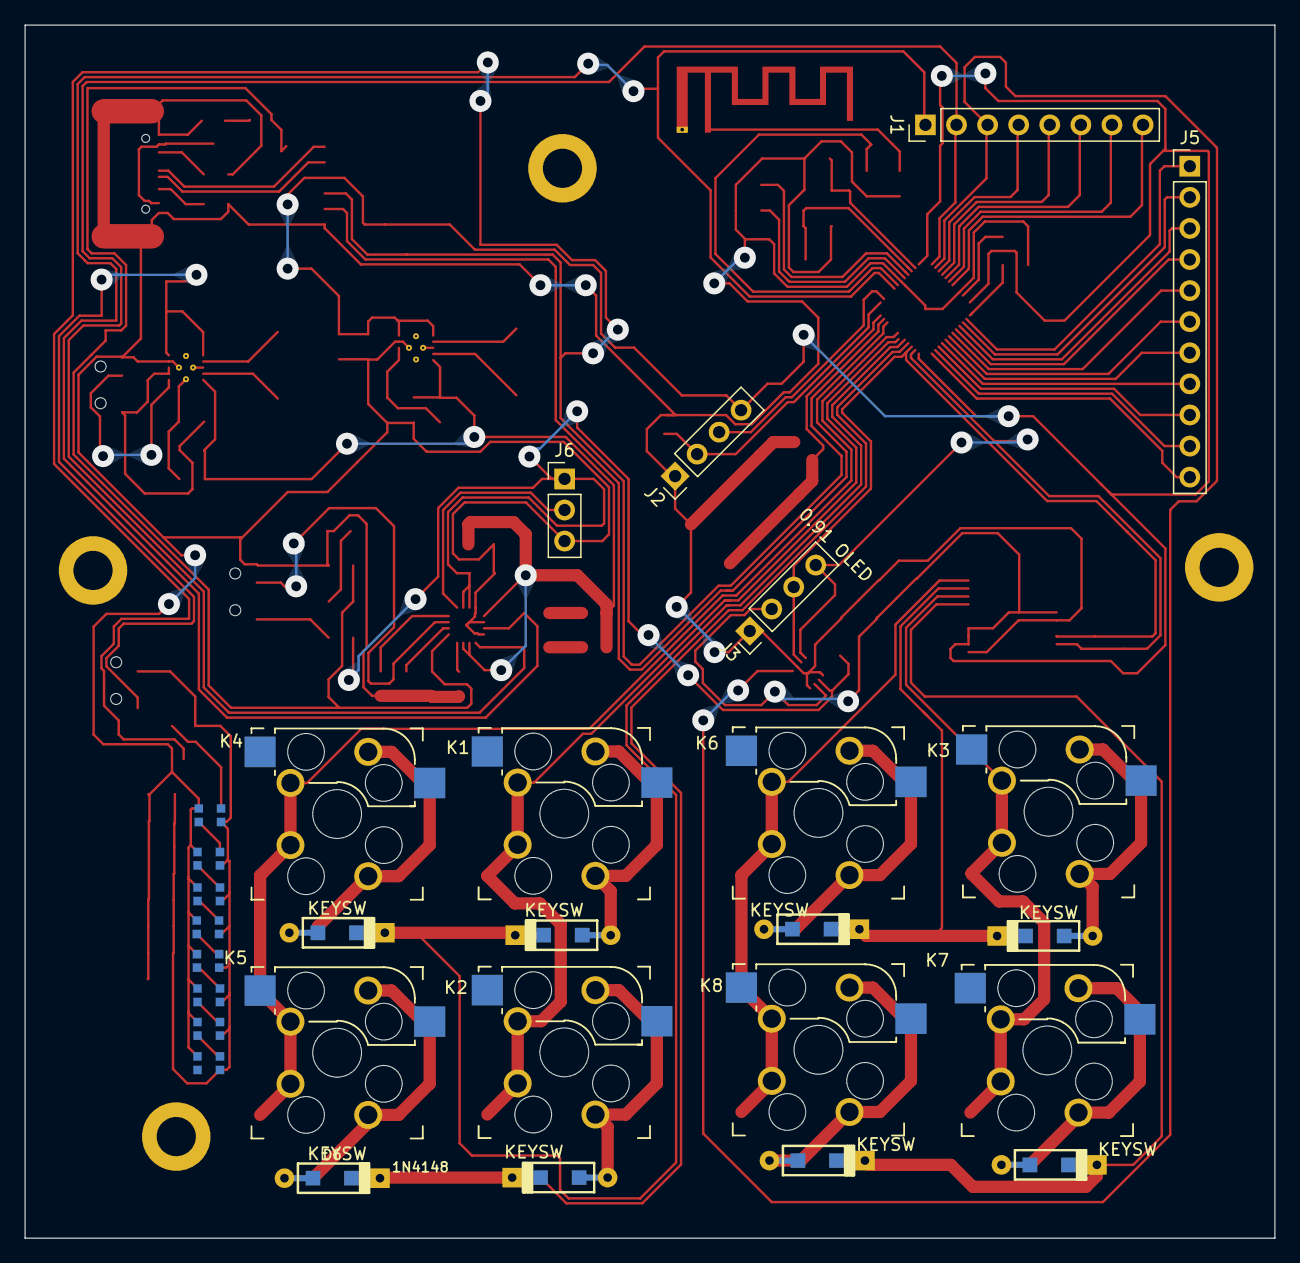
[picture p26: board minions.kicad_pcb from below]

Board: 2 copper layers, 102.1 x 99.1 mm, 105 parts (14 on the bottom side), 87 nets.

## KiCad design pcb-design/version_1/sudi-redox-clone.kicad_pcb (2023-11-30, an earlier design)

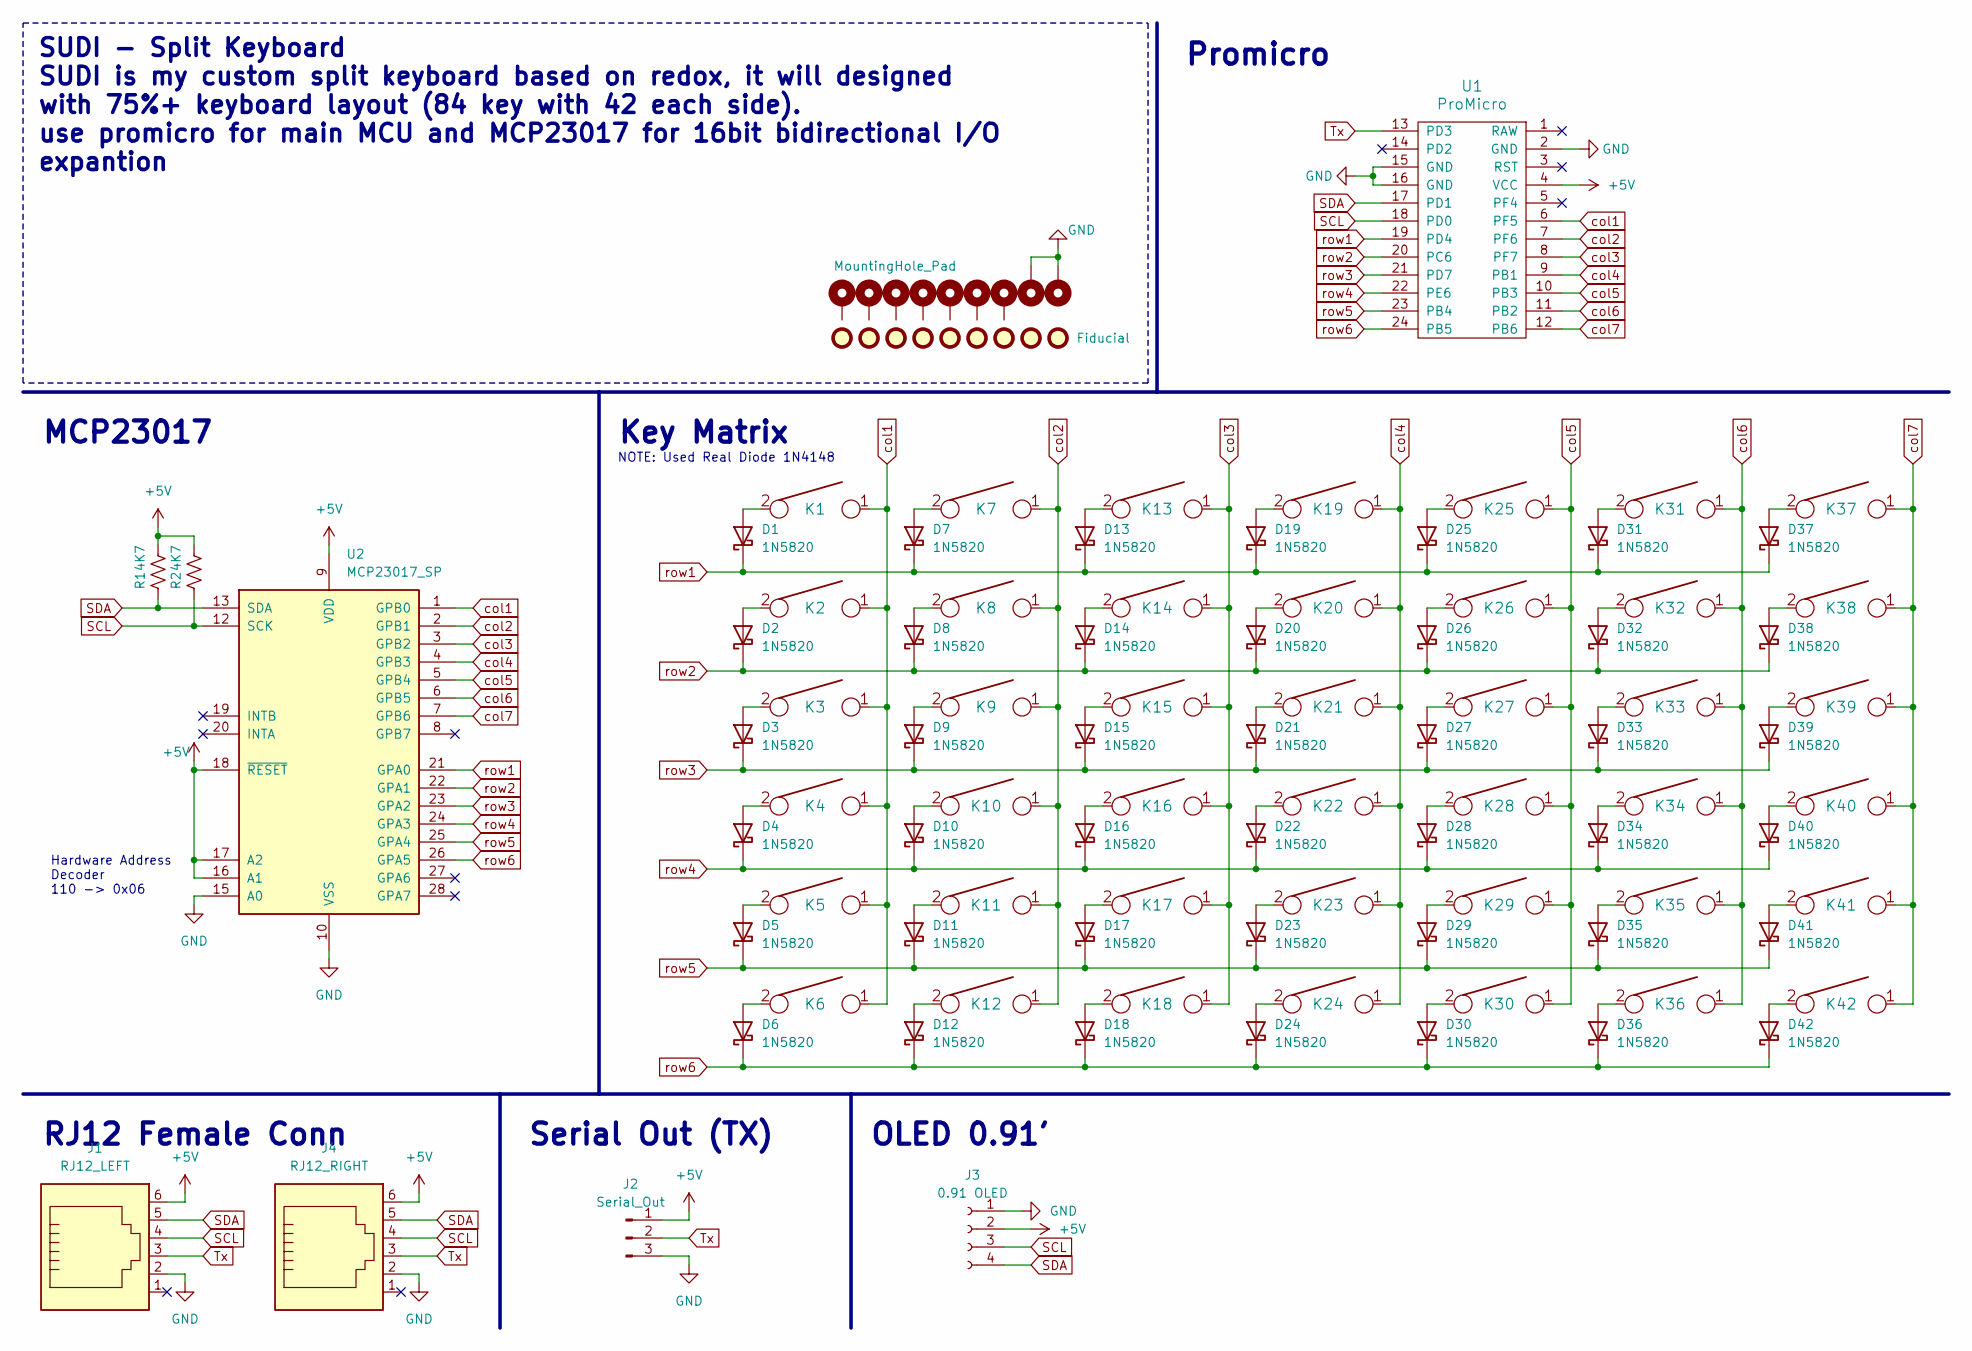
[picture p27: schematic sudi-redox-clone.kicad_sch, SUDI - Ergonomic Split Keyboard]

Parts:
D1, D2, D3, D4, D5, D6, D7, D8, D9, D10, D11, D12, D13, D14, D15, D16, D17, D18, D19, D20, D21, D22, D23, D24, D25, D26, D27, D28, D29, D30, D31, D32, D33, D34, D35, D36, D37, D38, D39, D40, D41, D42: 1N5820; D_SOD123_axial-dual
FID1, FID2, FID3, FID4, FID5, FID6, FID7, FID8, FID9: Fiducial; Fiducial_1mm_Mask3mm
H1, H2, H3, H4, H5, H6, H7, H8, H9: MountingHole_Pad; MountingHole_3.2mm_M3_DIN965_Pad
J1: RJ12_LEFT; RJ12_Amphenol_54601
J2: Serial_Out; PinHeader_1x03_P2.54mm_Horizontal
J3: 0.91 OLED; SSD1306-0.91-OLED-4pin-128x32
J4: RJ12_RIGHT; RJ12_Amphenol_54601
K1, K5, K6, K7, K8, K9, K10, K11, K12, K13, K14, K15, K16, K17, K18, K19, K20, K21, K22, K23, K24, K25, K26, K27, K28, K29, K30, K31, K32, K33, K34, K35, K36, K37, K38, K39, K40, K41, K42: KEYSW; Mx_Alps_100-dualside
K2, K3, K4: KEYSW; Mx_Alps_150-dualsided
R1, R2: 4K7; R_1206_3216Metric
U1: ProMicro; Pro_Micro
U2: MCP23017_SP; DIP-28_W7.62mm

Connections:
+5V: J1.6, J2.1, J3.2, J4.6, R1.1, R2.1, U1.4 (VCC), U2.9 (VDD), U2.16 (A1), U2.17 (A2), U2.18 (~RESET)
GND: H2.1, H9.1, J1.2, J2.3, J3.1, J4.2, U1.2 (GND), U1.15 (GND), U1.16 (GND), U2.10 (VSS), U2.15 (A0)
unnamed: D1.2 (A), K1.2
unnamed: D2.2 (A), K2.2
unnamed: D3.2 (A), K3.2
unnamed: D4.2 (A), K4.2
unnamed: D5.2 (A), K5.2
unnamed: D6.2 (A), K6.2
unnamed: D7.2 (A), K7.2
unnamed: D8.2 (A), K8.2
unnamed: D9.2 (A), K9.2
unnamed: D10.2 (A), K10.2
unnamed: D11.2 (A), K11.2
unnamed: D12.2 (A), K12.2
unnamed: D13.2 (A), K13.2
unnamed: D14.2 (A), K14.2
unnamed: D15.2 (A), K15.2
unnamed: D16.2 (A), K16.2
unnamed: D17.2 (A), K17.2
unnamed: D18.2 (A), K18.2
unnamed: D19.2 (A), K19.2
unnamed: D20.2 (A), K20.2
unnamed: D21.2 (A), K21.2
unnamed: D22.2 (A), K22.2
unnamed: D23.2 (A), K23.2
unnamed: D24.2 (A), K24.2
unnamed: D25.2 (A), K25.2
unnamed: D26.2 (A), K26.2
unnamed: D27.2 (A), K27.2
unnamed: D28.2 (A), K28.2
unnamed: D29.2 (A), K29.2
unnamed: D30.2 (A), K30.2
unnamed: D31.2 (A), K31.2
unnamed: D32.2 (A), K32.2
unnamed: D33.2 (A), K33.2
unnamed: D34.2 (A), K34.2
unnamed: D35.2 (A), K35.2
unnamed: D36.2 (A), K36.2
unnamed: D37.2 (A), K37.2
unnamed: D38.2 (A), K38.2
unnamed: D39.2 (A), K39.2
unnamed: D40.2 (A), K40.2
unnamed: D41.2 (A), K41.2
unnamed: D42.2 (A), K42.2
SCL: J1.4, J3.3, J4.4, R2.2, U1.18 (PD0), U2.12 (SCK)
SDA: J1.5, J3.4, J4.5, R1.2, U1.17 (PD1), U2.13 (SDA)
Tx: J1.3, J2.2, J4.3, U1.13 (PD3)
col1: K1.1, K2.1, K3.1, K4.1, K5.1, K6.1, U1.6 (PF5), U2.1 (GPB0)
col2: K7.1, K8.1, K9.1, K10.1, K11.1, K12.1, U1.7 (PF6), U2.2 (GPB1)
col3: K13.1, K14.1, K15.1, K16.1, K17.1, K18.1, U1.8 (PF7), U2.3 (GPB2)
col4: K19.1, K20.1, K21.1, K22.1, K23.1, K24.1, U1.9 (PB1), U2.4 (GPB3)
col5: K25.1, K26.1, K27.1, K28.1, K29.1, K30.1, U1.10 (PB3), U2.5 (GPB4)
col6: K31.1, K32.1, K33.1, K34.1, K35.1, K36.1, U1.11 (PB2), U2.6 (GPB5)
col7: K37.1, K38.1, K39.1, K40.1, K41.1, K42.1, U1.12 (PB6), U2.7 (GPB6)
row1: D1.1 (K), D7.1 (K), D13.1 (K), D19.1 (K), D25.1 (K), D31.1 (K), D37.1 (K), U1.19 (PD4), U2.21 (GPA0)
row2: D2.1 (K), D8.1 (K), D14.1 (K), D20.1 (K), D26.1 (K), D32.1 (K), D38.1 (K), U1.20 (PC6), U2.22 (GPA1)
row3: D3.1 (K), D9.1 (K), D15.1 (K), D21.1 (K), D27.1 (K), D33.1 (K), D39.1 (K), U1.21 (PD7), U2.23 (GPA2)
row4: D4.1 (K), D10.1 (K), D16.1 (K), D22.1 (K), D28.1 (K), D34.1 (K), D40.1 (K), U1.22 (PE6), U2.24 (GPA3)
row5: D5.1 (K), D11.1 (K), D17.1 (K), D23.1 (K), D29.1 (K), D35.1 (K), D41.1 (K), U1.23 (PB4), U2.25 (GPA4)
row6: D6.1 (K), D12.1 (K), D18.1 (K), D24.1 (K), D30.1 (K), D36.1 (K), D42.1 (K), U1.24 (PB5), U2.26 (GPA5)

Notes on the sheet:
SUDI - Split Keyboard SUDI is my custom split keyboard based on redox, it will designed with 75%+ keyboard layout (84 key with 42 each side). use promicro for main MCU and MCP23017 for 16bit bidirectional I/O expantion
Key Matrix
NOTE: Used Real Diode 1N4148
Serial Out (TX)
Hardware Address Decoder 110 -> 0x06
RJ12 Female Conn
OLED 0.91'
MCP23017
Promicro

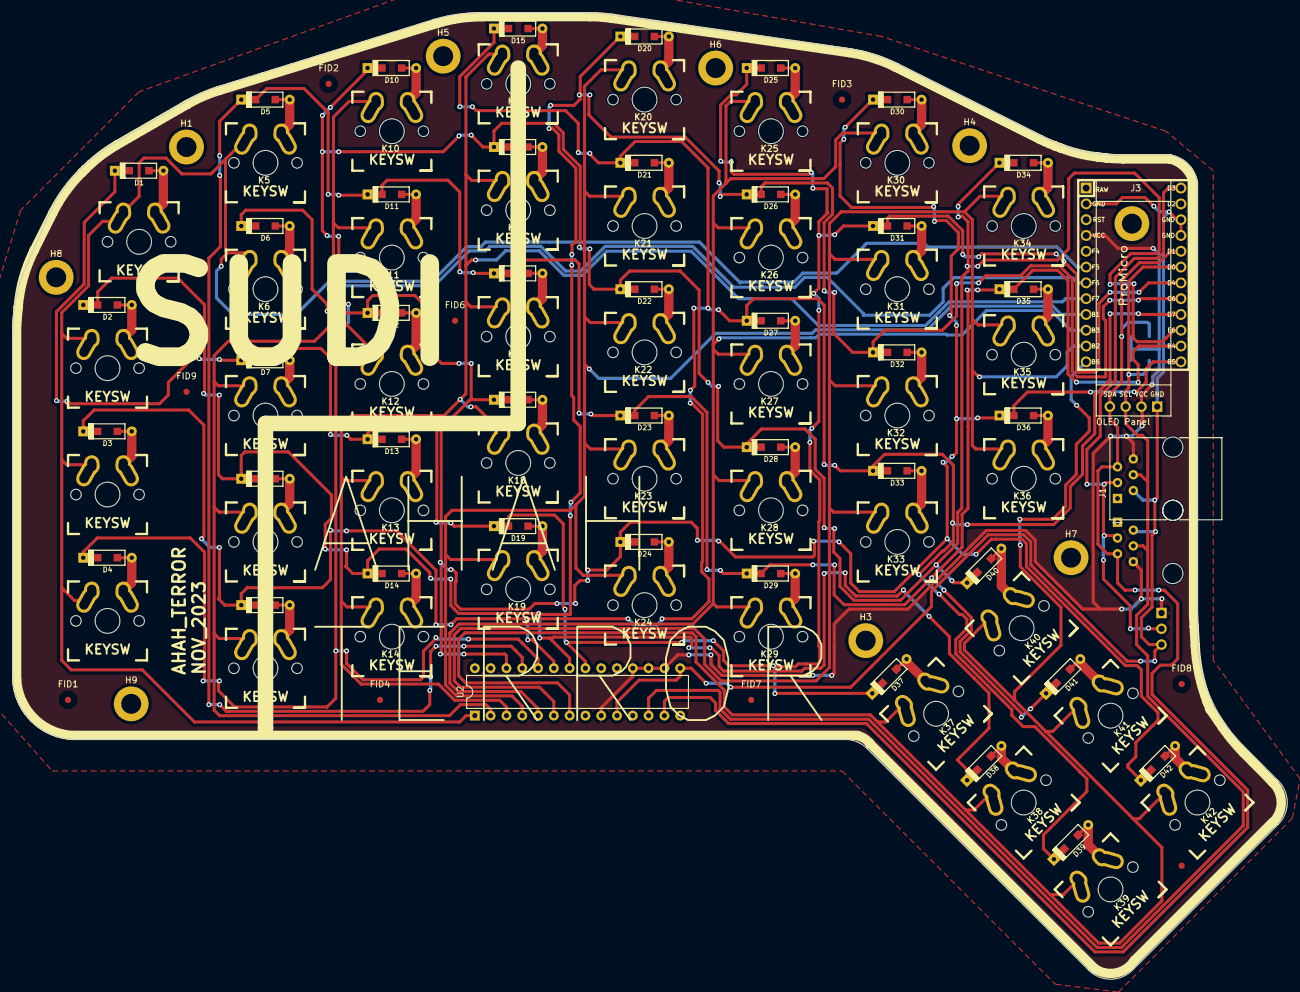
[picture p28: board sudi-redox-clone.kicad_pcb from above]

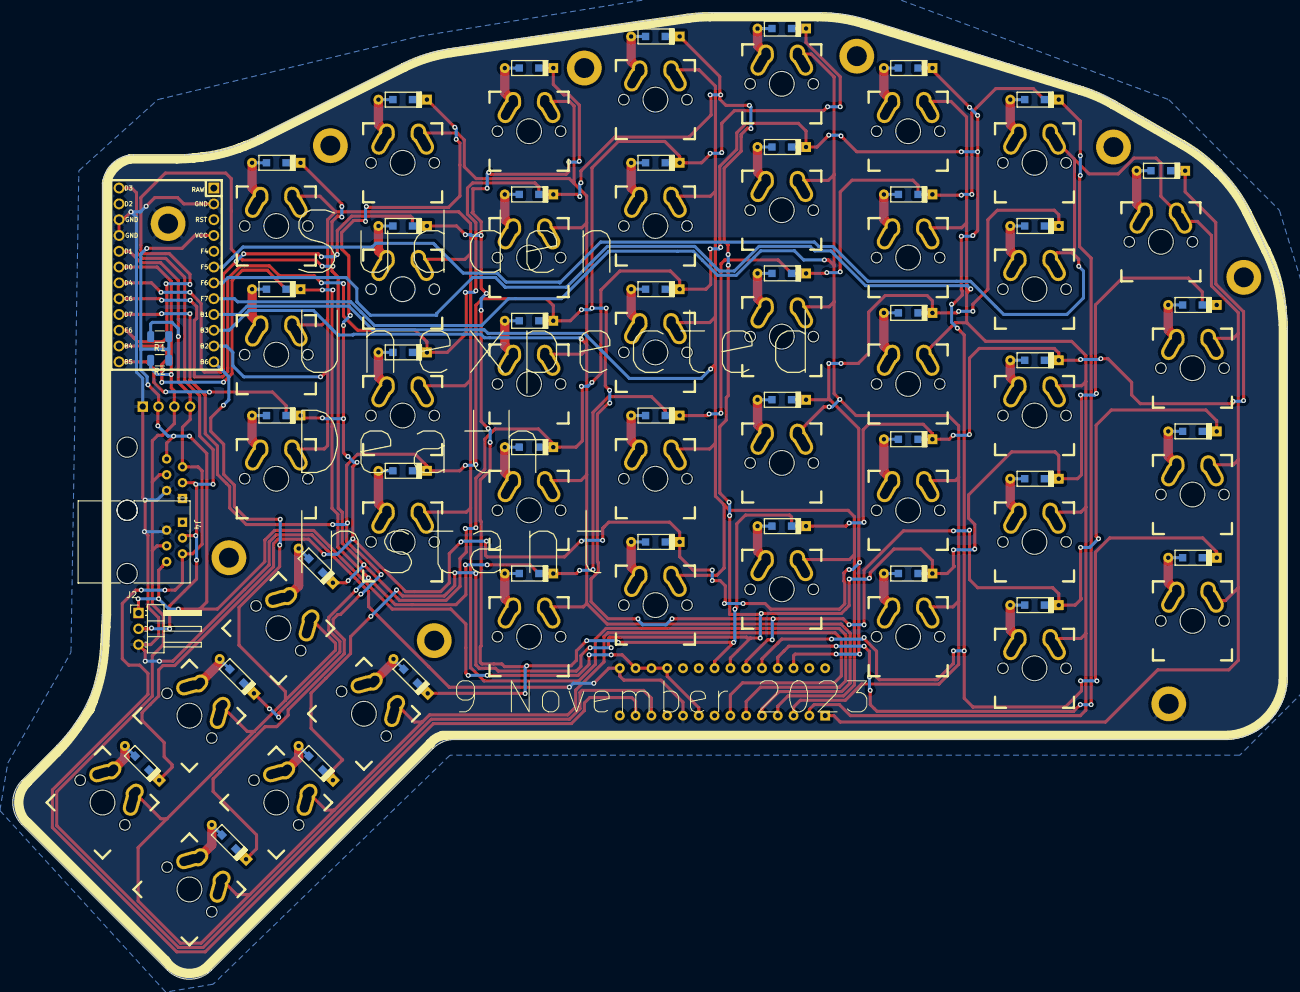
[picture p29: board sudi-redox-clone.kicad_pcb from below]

Board: 2 copper layers, 204.9 x 155.4 mm, 110 parts (4 on the bottom side), 60 nets.

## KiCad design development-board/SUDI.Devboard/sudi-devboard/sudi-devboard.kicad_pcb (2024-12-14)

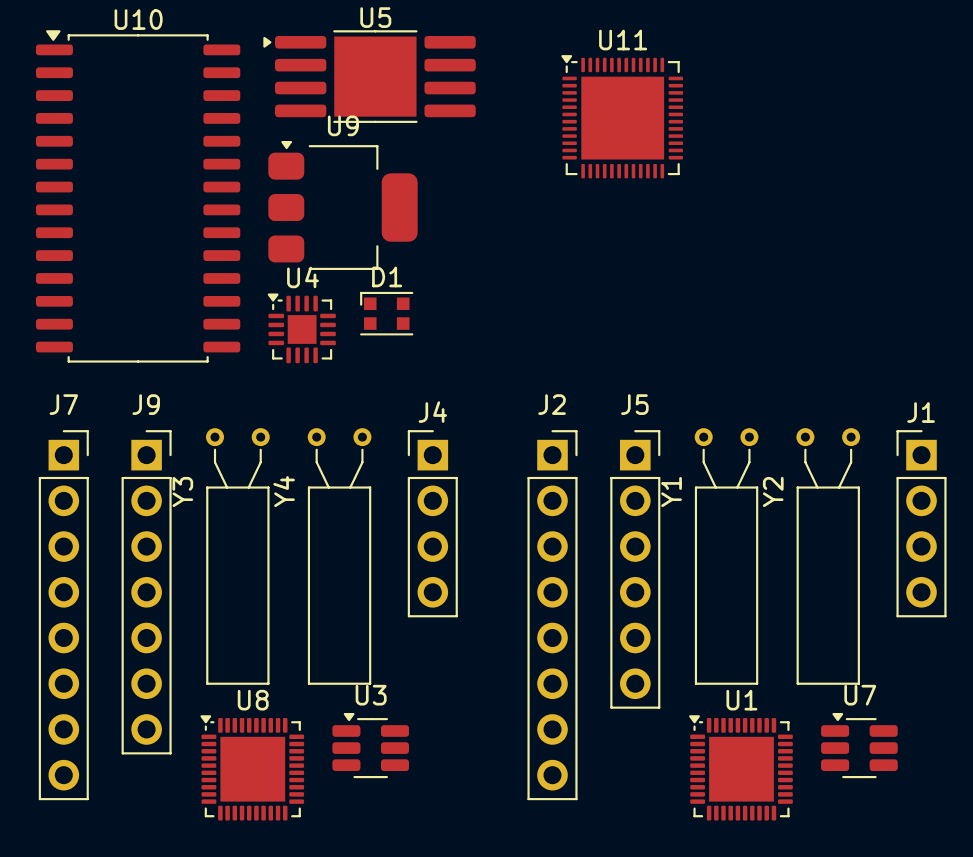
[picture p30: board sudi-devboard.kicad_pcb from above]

Board: 2 copper layers, 20 parts (0 on the bottom side), 54 nets, no tracks yet.

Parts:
D1: WS2812B-2020; LED_WS2812B-2020_PLCC4_2.0x2.0mm
J1, J4: SWD_JLINK; PinHeader_1x04_P2.54mm_Vertical
J2, J7: Conn_01x08_Pin; PinSocket_1x08_P2.54mm_Vertical
J5: Conn_01x06_Pin; PinSocket_1x06_P2.54mm_Vertical
J9: Conn_01x07_Pin; PinSocket_1x07_P2.54mm_Vertical
U1: nRF52833_QDxx; QFN-40-1EP_5x5mm_P0.4mm_EP3.6x3.6mm
U3, U7: SRV05-4; SOT-23-6_Handsoldering
U4: BQ24075RGT; VQFN-16-1EP_3x3mm_P0.5mm_EP1.6x1.6mm
U5: TP4056; SOP-8-1EP_4.57x4.57mm_P1.27mm_EP4.57x4.45mm
U8: nRF52820-QDxx; QFN-40-1EP_5x5mm_P0.4mm_EP3.6x3.6mm
U9: AMS1117-3.3; SOT-223-3_TabPin2
U10: MCP23017_SO; SOIC-28W_7.5x17.9mm_P1.27mm
U11: nRF52832-QFxx; QFN-48-1EP_6x6mm_P0.4mm_EP4.6x4.6mm
Y1, Y3: 32Mhz; Crystal_AT310_D3.0mm_L10.0mm_Horizontal
Y2, Y4: 32.768kHz; Crystal_AT310_D3.0mm_L10.0mm_Horizontal

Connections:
/NRF52820/AIN0/P0.02: J7.1, U8.36 (AIN0/P0.02)
/NRF52820/AIN1/P0.03: J7.2, U8.35 (AIN1/P0.03)
/NRF52820/AIN2/P0.04: J7.3, U8.4 (AIN2/P0.04)
/NRF52820/AIN3/P0.05: J7.4, U8.5 (AIN3/P0.05)
/NRF52820/D+: U3.6 (IO4), U8.13 (D+)
/NRF52820/D-: U3.1 (IO1), U8.12 (D-)
/NRF52820/P0.06: J7.5, U8.6 (P0.06)
/NRF52820/P0.07: J7.6, U8.7 (P0.07)
/NRF52820/P0.08: J7.7, U8.31 (P0.08)
/NRF52820/P0.14: J7.8, U8.14 (P0.14)
/NRF52820/P0.15: J9.1, U8.15 (P0.15)
/NRF52820/P0.16: J9.2, U8.22 (P0.16)
/NRF52820/P0.17: J9.3, U8.23 (P0.17)
/NRF52820/P0.20: J9.4, U8.17 (P0.20)
/NRF52820/P0.28: J9.5, U8.34 (P0.28)
/NRF52820/P0.29: J9.6, U8.32 (P0.29)
/NRF52820/P0.30: J9.7, U8.33 (P0.30)
/NRF52820/SWDCLK: J4.2, U8.20 (SWDCLK)
/NRF52820/SWDIO: J4.3, U8.19 (SWDIO)
/NRF52820/XC1: U8.28 (XC1), Y3.1
/NRF52820/XC2: U8.29 (XC2), Y3.2
/NRF52820/XL1/P0.00: U8.2 (XL1/P0.00), Y4.1
/NRF52820/XL2/P0.01: U8.3 (XL2/P0.01), Y4.2
/NRF52833_QFN40/AIN0/P0.02: J2.1, U1.32 (AIN0/P0.02)
/NRF52833_QFN40/AIN1/P0.03: J2.2, U1.31 (AIN1/P0.03)
/NRF52833_QFN40/AIN2/P0.04: J2.3, U1.4 (AIN2/P0.04)
/NRF52833_QFN40/AIN3/P0.05: J2.4, U1.5 (AIN3/P0.05)
/NRF52833_QFN40/AIN4/P0.28: J5.3, U1.33 (AIN4/P0.28)
/NRF52833_QFN40/AIN5/P0.29: J5.4, U1.34 (AIN5/P0.29)
/NRF52833_QFN40/AIN6/P0.30: J5.5, U1.35 (AIN6/P0.30)
/NRF52833_QFN40/AIN7/P0.31: J5.6, U1.36 (AIN7/P0.31)
/NRF52833_QFN40/D+: U1.13 (D+), U7.6 (IO4)
/NRF52833_QFN40/D-: U1.12 (D-), U7.1 (IO1)
/NRF52833_QFN40/NFC1/P0.09: J2.5, U1.22 (NFC1/P0.09)
/NRF52833_QFN40/NFC2/P0.10: J2.6, U1.23 (NFC2/P0.10)
/NRF52833_QFN40/P0.11: J2.7, U1.7 (P0.11)
/NRF52833_QFN40/P0.15: J2.8, U1.14 (P0.15)
/NRF52833_QFN40/P0.17: J5.1, U1.15 (P0.17)
/NRF52833_QFN40/P0.20: J5.2, U1.17 (P0.20)
/NRF52833_QFN40/SWDCLK: J1.2, U1.20 (SWDCLK)
/NRF52833_QFN40/SWDIO: J1.3, U1.19 (SWDIO)
/NRF52833_QFN40/XC1: U1.28 (XC1), Y1.1
/NRF52833_QFN40/XC2: U1.29 (XC2), Y1.2
/NRF52833_QFN40/XL1/P0.00: U1.2 (XL1/P0.00), Y2.1
/NRF52833_QFN40/XL2/P0.01: U1.3 (XL2/P0.01), Y2.2
GND: J1.1, J4.1, U1.25 (VSS_PA), U1.37 (VSS), U1.41 (VSS), U3.2 (VN), U7.2 (VN), U8.25 (VSS_PA), U8.37 (VSS), U8.41 (VSS)
unnamed: U1.26 (DEC6), U1.38 (DEC4)
unnamed: U4.2 (BAT), U4.3 (BAT)
unnamed: U4.10 (OUT), U4.11 (OUT)
unnamed: U4.8 (VSS), U4.17 (VSS)
unnamed: U11.13 (VDD), U11.36 (VDD), U11.48 (VDD)
unnamed: U11.31 (VSS), U11.45 (VSS), U11.49 (VSS)
VBUS: U1.9 (VDDH), U1.10 (VBUS), U3.5 (VP), U7.5 (VP)
VDD: J1.4, J4.4, U1.8 (VDD), U1.18 (VDD), U1.30 (VDD), U1.40 (VDD)

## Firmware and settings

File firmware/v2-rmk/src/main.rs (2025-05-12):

#![no_std]
#![no_main]
//
// mod vial;
// #[macro_use]
// mod macros;
// mod keymap;
//
// use defmt::{info, unwrap};
// use embassy_executor::Spawner;
// use embassy_nrf::gpio::{Input, Output};
// use embassy_nrf::peripherals::RNG;
// use embassy_nrf::{bind_interrupts, rng};
// use keymap::{COL, ROW};
// use nrf_mpsl::Flash;
// use nrf_sdc::mpsl::MultiprotocolServiceLayer;
// use nrf_sdc::{self as sdc, mpsl};
// use rand_chacha::ChaCha12Rng;
// use rand_core::SeedableRng;
// use rmk::ble::trouble::build_ble_stack;
// use rmk::channel::EVENT_CHANNEL;
// use rmk::config::{
//     BehaviorConfig, ControllerConfig, KeyboardUsbConfig, RmkConfig, StorageConfig, VialConfig,
// };
// use rmk::debounce::default_debouncer::DefaultDebouncer;
// use rmk::futures::future::join3;
// use rmk::input_device::Runnable as _;
// use rmk::keyboard::Keyboard;
// use rmk::light::LightController;
// use rmk::matrix::Matrix;
// use rmk::{initialize_keymap_and_storage, run_devices, run_rmk, HostResources};
// use static_cell::StaticCell;
// use vial::{VIAL_KEYBOARD_DEF, VIAL_KEYBOARD_ID};
// use {defmt_rtt as _, panic_probe as _};
//
// bind_interrupts!(struct Irqs {
//     RNG => rng::InterruptHandler<RNG>;
//     EGU0_SWI0 => nrf_sdc::mpsl::LowPrioInterruptHandler;
//     CLOCK_POWER => nrf_sdc::mpsl::ClockInterruptHandler;
//     RADIO => nrf_sdc::mpsl::HighPrioInterruptHandler;
//     TIMER0 => nrf_sdc::mpsl::HighPrioInterruptHandler;
//     RTC0 => nrf_sdc::mpsl::HighPrioInterruptHandler;
// });
//
// #[embassy_executor::task]
// async fn mpsl_task(mpsl: &'static MultiprotocolServiceLayer<'static>) -> ! {
//     mpsl.run().await
// }
//
// /// How many outgoing L2CAP buffers per link
// const L2CAP_TXQ: u8 = 3;
//
// /// How many incoming L2CAP buffers per link
// const L2CAP_RXQ: u8 = 3;
//
// /// Size of L2CAP packets
// const L2CAP_MTU: usize = 72;
//
// fn build_sdc<'d, const N: usize>(
//     p: nrf_sdc::Peripherals<'d>,
//     rng: &'d mut rng::Rng<RNG>,
//     mpsl: &'d MultiprotocolServiceLayer,
//     mem: &'d mut sdc::Mem<N>,
// ) -> Result<nrf_sdc::SoftdeviceController<'d>, nrf_sdc::Error> {
//     sdc::Builder::new()?
//         .support_adv()?
//         .support_peripheral()?
//         .peripheral_count(1)?
//         .buffer_cfg(L2CAP_MTU as u8, L2CAP_MTU as u8, L2CAP_TXQ, L2CAP_RXQ)?
//         .build(p, rng, mpsl, mem)
// }
//
// fn ble_addr() -> [u8; 6] {
//     let ficr = embassy_nrf::pac::FICR;
//     let high = u64::from(ficr.deviceid(1).read());
//     let addr = high << 32 | u64::from(ficr.deviceid(0).read());
//     let addr = addr | 0x0000_c000_0000_0000;
//     unwrap!(addr.to_le_bytes()[..6].try_into())
// }
//
// #[embassy_executor::main]
// async fn main(spawner: Spawner) {
//     info!("Hello RMK BLE!");
//     // Initialize the peripherals and nrf-sdc controller
//     let p = embassy_nrf::init(Default::default());
//     let mpsl_p =
//         mpsl::Peripherals::new(p.RTC0, p.TIMER0, p.TEMP, p.PPI_CH19, p.PPI_CH30, p.PPI_CH31);
//     let lfclk_cfg = mpsl::raw::mpsl_clock_lfclk_cfg_t {
//         source: mpsl::raw::MPSL_CLOCK_LF_SRC_RC as u8,
//         rc_ctiv: mpsl::raw::MPSL_RECOMMENDED_RC_CTIV as u8,
//         rc_temp_ctiv: mpsl::raw::MPSL_RECOMMENDED_RC_TEMP_CTIV as u8,
//         accuracy_ppm: mpsl::raw::MPSL_DEFAULT_CLOCK_ACCURACY_PPM as u16,
//         skip_wait_lfclk_started: mpsl::raw::MPSL_DEFAULT_SKIP_WAIT_LFCLK_STARTED != 0,
//     };
//     static MPSL: StaticCell<MultiprotocolServiceLayer> = StaticCell::new();
//     static SESSION_MEM: StaticCell<mpsl::SessionMem<1>> = StaticCell::new();
//     let mpsl = MPSL.init(unwrap!(mpsl::MultiprotocolServiceLayer::with_timeslots(
//         mpsl_p,
//         Irqs,
//         lfclk_cfg,
//         SESSION_MEM.init(mpsl::SessionMem::new())
//     )));
//     spawner.must_spawn(mpsl_task(&*mpsl));
//     let sdc_p = sdc::Peripherals::new(
//         p.PPI_CH17, p.PPI_CH18, p.PPI_CH20, p.PPI_CH21, p.PPI_CH22, p.PPI_CH23, p.PPI_CH24,
//         p.PPI_CH25, p.PPI_CH26, p.PPI_CH27, p.PPI_CH28, p.PPI_CH29,
//     );
//     let mut rng = rng::Rng::new(p.RNG, Irqs);
//     let mut rng_gen = ChaCha12Rng::from_rng(&mut rng).unwrap();
//     let mut sdc_mem = sdc::Mem::<3072>::new();
//     let sdc = unwrap!(build_sdc(sdc_p, &mut rng, mpsl, &mut sdc_mem));
//     let mut host_resources = HostResources::new();
//     let stack = build_ble_stack(sdc, ble_addr(), &mut rng_gen, &mut host_resources).await;
//
//     // Initialize flash
//     let flash = Flash::take(mpsl, p.NVMC);
//
//     // Initialize IO Pins
//     let (input_pins, output_pins) = config_matrix_pins_nrf!(peripherals: p, input: [P0_30, P0_31, P0_29, P0_27], output:  [P0_28, P0_03, P0_11]);
//
//     // Keyboard config
//     let keyboard_usb_config = KeyboardUsbConfig {
//         vid: 0x4c4b,
//         pid: 0x4643,
//         manufacturer: "Haobo",
//         product_name: "RMK Keyboard",
//         serial_number: "vial:f64c2b3c:000001",
//     };
//     let vial_config = VialConfig::new(VIAL_KEYBOARD_ID, VIAL_KEYBOARD_DEF);
//     let storage_config = StorageConfig {
//         start_addr: 0x70000,
//         num_sectors: 6,
//         ..Default::default()
//     };
//     let rmk_config = RmkConfig {
//         usb_config: keyboard_usb_config,
//         vial_config,
//         storage_config,
//         ..Default::default()
//     };
//
//     // Initialze keyboard stuffs
//     // Initialize the storage and keymap
//     let mut default_keymap = keymap::get_default_keymap();
//     let behavior_config = BehaviorConfig::default();
//     let (keymap, mut storage) =
//         initialize_keymap_and_storage(&mut default_keymap, flash, &storage_config, behavior_config)
//             .await;
//
//     // Initialize the matrix and keyboard
//     let debouncer = DefaultDebouncer::<ROW, COL>::new();
//     let mut matrix = Matrix::<_, _, _, ROW, COL>::new(input_pins, output_pins, debouncer);
//     // let mut matrix = TestMatrix::<ROW, COL>::new();
//     let mut keyboard = Keyboard::new(&keymap);
//
//     // Initialize the light controller
//     let mut light_controller: LightController<Output> =
//         LightController::new(ControllerConfig::default().light_config);
//
//     join3(
//         run_devices! (
//             (matrix) => EVENT_CHANNEL,
//         ),
//         keyboard.run(), // Keyboard is special
//         run_rmk(
//             &keymap,
//             &stack,
//             &mut storage,
//             &mut light_controller,
//             rmk_config,
//         ),
//     )
//     .await;
// }

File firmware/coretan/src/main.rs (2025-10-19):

use coretan::event_type::*;

fn main() {
    let events = vec![
        Event::BatteryEvent(Some(BatteryEventData { percent: 10 })),
        Event::KeyEvent(Some(KeyEventData { character: 'C' })),
        Event::BatteryEvent(Some(BatteryEventData { percent: 50 })),
        Event::KeyEvent(Some(KeyEventData { character: 'A' })),
        // Event::HostEvent(Some(HostEventData { data: 'A' })),
    ];

    let event_handlers: [&dyn HandlerCorTrait<HandlingType = HandlerTypeEnum>; 2] =
        [&KeyEventHandler::default(), &BatteryEventHandler::default()];

    for event in events {
        let handler = event_handlers
            .iter()
            .find(|&&pr| pr.handling_type() == event.get_type());

        if handler.is_none() {
            panic!("cant find event handler for {event:#?}")
        }

        handler.unwrap().handle(&event);
    }
}

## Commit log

2023-11-04 create schematic
    [sudi-redox-clone.kicad_pcb, sudi-redox-clone.kicad_sch]
2023-11-04 rename folder from sudi-redox-clone to pcb-design
    [sudi-redox-clone.kicad_pcb, sudi-redox-clone.kicad_sch]
2023-11-08 generate gerber and routed board rev 0.1
    [SUDI-Casing.FCStd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]
2023-11-12 adding firmware from symlink
    [sudi-redox-clone-B_Cu.gbr, sudi-redox-clone-B_Mask.gbr, sudi-redox-clone-B_Paste.gbr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]
2023-11-18 generate dxf file - 1
    [sudi-redox-clone-B_Silkscreen.dxf, sudi-redox-clone-Edge_Cuts.dxf, sudi-redox-clone-NPTH-drl_map.dxf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]
2023-11-18 generate stepfile - 1
    [sudi-redox-clone.kicad_pcb]
2023-11-19 add keycap cut guide - 1
    [sudi-redox-clone-User_Drawings.dxf]
2023-11-30 physical keyboard made with revision - see nb
    [sudi-redox-clone.kicad_pcb]
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2023-12-21 add casing to repo
    [128x32-OLED.STEP, SUDI-Casing.FCStd, keyboarddrawing.dxf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]
2024-12-14 [jumat 28 juni 2024] sudi v2 started
    [sudi-redox-clone.kicad_sch]
2024-12-14 add canadian library to repo
    [sudi-redox-clone.kicad_pcb]
2024-12-14 add several component to schematic
    [sudi-redox-clone.kicad_sch]
2024-12-14 add nordic design Reference
    [400342.DRL, 400342.GBL, 400342.GBO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]
2024-12-14 [minggu 7 juli 7:27] create receiver schematic
    [Receiver.kicad_sch, sudi-redox-clone.kicad_sch]
2024-12-14 [minggu 7 juli 8:55] cleaning schematic layout
    [Receiver.kicad_sch, sudi-redox-clone.kicad_sch]
2024-12-14 [minggu 7 juli 12:12] create pcb cut profile
    [Receiver.kicad_sch, sudi-redox-clone.kicad_pcb, sudi-redox-clone.kicad_sch]
2024-12-14 [minggu 7 juli 19:32] finish PCB Layout
    [Receiver.kicad_sch, sudi-redox-clone.kicad_pcb, sudi-redox-clone.kicad_sch]
2024-12-14 add some route progress
    [sudi-redox-clone.kicad_pcb, sudi-redox-clone.kicad_sch]
2024-12-14 update some route
    [sudi-redox-clone.kicad_pcb]
2024-12-14 [rabu 17 juli 19:13] update route progress
    [sudi-redox-clone.kicad_pcb]
2024-12-14 [rabu 24 juli 20:17] finish keyboard layout - todo receiver
    [sudi-redox-clone.kicad_pcb, sudi-redox-clone.kicad_sch]
2024-12-14 finsihed receiver route
    [sudi-redox-clone.kicad_pcb]
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2024-12-14 change NRF51822 into NRF52832
    [sudi-redox-clone.kicad_pcb, sudi-redox-clone.kicad_sch]
2024-12-14 updateRoute to use NRF52832
    [sudi-redox-clone.kicad_pcb, sudi-redox-clone.kicad_sch]
2024-12-14 add CH340C
    [sudi-redox-clone.kicad_pcb, sudi-redox-clone.kicad_sch]
2024-12-14 [11-01-1954] add test point into NRF
    [Receiver.kicad_sch, sudi-redox-clone.kicad_pcb, sudi-redox-clone.kicad_sch]
2024-12-14 [11-13-0459] add svg and switch to schematic
    [sudi-redox-clone.kicad_sch]
2024-12-14 [14-11-2129] init SUDI development board
    nit
    [NRF52820.kicad_sch, NRF52832.kicad_sch, NRF52833_QFN40.kicad_sch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]
2024-12-14 [16-11-1807] change chargin mechanism
    [Receiver.kicad_sch, sudi-redox-clone.kicad_pcb, sudi-redox-clone.kicad_sch]
2024-12-14 [16-11-1807] add capacitor to WS2812C-2020
    change gif
    [sudi-redox-clone.kicad_pcb, sudi-redox-clone.kicad_sch]
2024-12-14 [17-11-1825] tweak values and silkscreen
    nit, add pdf
    nit schematic
    add svg
    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
    [sudi-redox-clone.kicad_pcb, sudi-redox-clone.kicad_sch, sudi-v2-bom.csv]
2024-12-14 [20-11-2007] create LCSC Cart from BOM
    [sudi-redox-clone.kicad_pcb]
2024-12-14 [12-13-2203] combine wired version 1 with version 2
    Update README.md
    Update README_V1.md
    update license
    Create LICENSE
    [128x32-OLED.STEP, Receiver.kicad_sch, keyboarddrawing.dxf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]
2024-12-16 [12-16-2150] add capacitor to anntena
    renamed kicad project
    [sudi-keyboard.kicad_pcb, sudi-keyboard.kicad_sch]
2025-01-19 [01-19-2213] generate gerber and order pcb
    [sudi-keyboard-B_Adhesive.gbr, sudi-keyboard-B_Courtyard.gbr, sudi-keyboard-B_Cu.gbr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]
2025-02-08 [02-08-1952] Ordering Component From LCSC
    [Receiver.kicad_sch, sudi-keyboard.kicad_pcb, sudi-keyboard.kicad_sch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]
2025-05-01 [05-01-0821] rechecking casing enclosure
    [enclosure.stl]
2025-05-09 [05-09-1013] gerber is not up to date, there is short circuit between 3.3 and gnd
    [sudi-keyboard.kicad_pcb]
2025-05-10 [05-09-2035] delete gerber and un-needed file from version 2 folder
    [sudi-keyboard-B_Adhesive.gbr, sudi-keyboard-B_Courtyard.gbr, sudi-keyboard-B_Cu.gbr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]
2025-05-12 [05-12-1100] first try to read direct pin matrix worked
    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
2025-05-12 [05-12-1200] move direct pin reader in its own struct
2025-05-13 [05-12-1755] inductor in sepic 5v is burnout :(
    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
2025-05-25 [05-25-1535] trying to run basic battery services, no luck
2025-05-25 [05-25-1901] add bleak to reading battery service, work but mostly intermitent
    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
2025-08-23 feat(component): change component to correct size
    [sudi-keyboard.kicad_pcb, sudi-keyboard.kicad_sch]
2025-08-25 feat: add 'minions' small version of sudi v2
    [minions.kicad_pcb, minions.kicad_sch]
2025-08-28 feat: routing minions part 1
    [minions.kicad_pcb, minions.kicad_sch]
2025-08-30 feat: finish routing part 1
    [minions.kicad_pcb, minions.kicad_sch]
2025-08-30 feat: add fabrication file
    [minions-B_Adhesive.gbr, minions-B_Courtyard.gbr, minions-B_Cu.gbr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]
2025-08-30 feat: fabricate first minions pcb, its going well
    [minions-B_Adhesive.gbr, minions-B_Courtyard.gbr, minions-B_Cu.gbr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]
